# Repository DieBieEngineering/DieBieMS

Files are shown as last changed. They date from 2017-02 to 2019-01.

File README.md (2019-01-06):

DieBieMS - Hardware
===
# Introduction
My personal transportation environment is becoming more and more electrical. All my new vehicles so far contain Lithium based batteries and need some form of automated management to be utilized in a safe and easy way. All affordable alternatives that I could find were either to dangerous(extreme cell voltage limits), couldn't carry the desired current (>70A), not compact enough or were not customizable. With this fully opensource project I would like to contribute to a more safe and affordable Lithium based electric vehicle (or possible other usage) future.

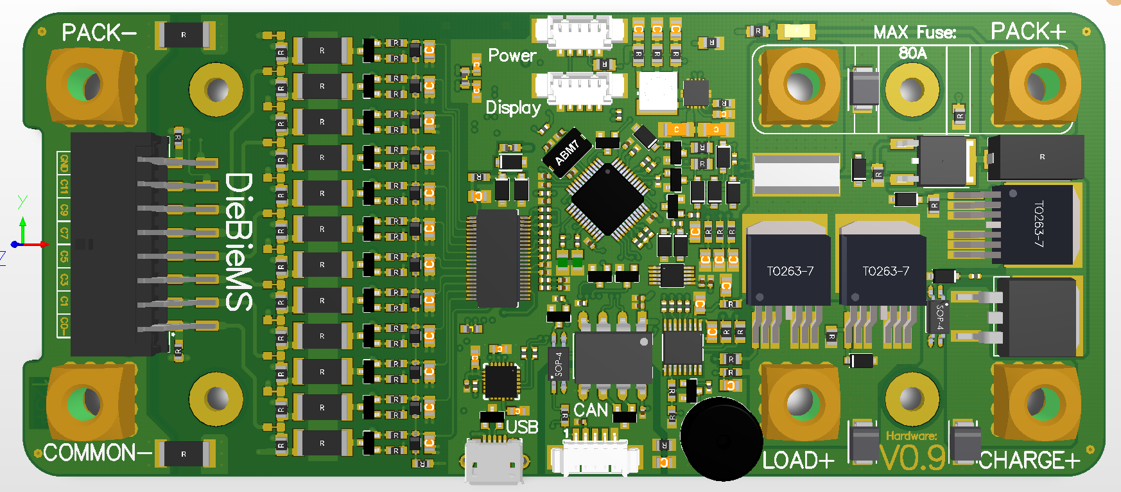
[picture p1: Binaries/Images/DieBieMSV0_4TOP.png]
DieBieMS V0.4 TopView


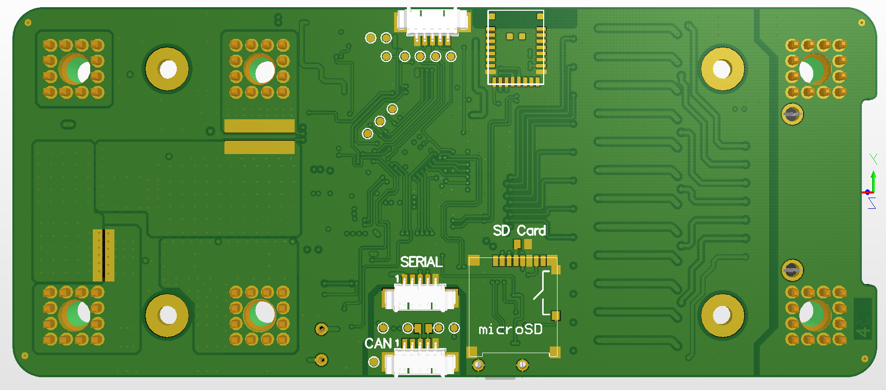
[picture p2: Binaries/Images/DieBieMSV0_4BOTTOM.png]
DieBieMS V0.4 BottomView


### Other parts of this project
This is the hardware repository containing all hardware source files (designed in altium) and the project outputs to build a BMS PCB. There are three more repositories for this project:<br>
[DieBieMS Firmware](https://github.com/DieBieEngineering/DieBieMS-Firmware) has to be flashed to the empty BMS STM32, the build .bin and hex file can be found in the BMS tool [resource folder](https://github.com/DieBieEngineering/DieBieMS-Tool/tree/master/res/firmwares).<br>
[DieBieMS Bootloader](https://github.com/DieBieEngineering/DieBieMS-Bootloader) can be flashed with the BMS Tool in the firmware tab.<br>
[DieBieMS Configuration tool](https://github.com/DieBieEngineering/DieBieMS-Tool) the tool to configure the BMS and upload the bootloader / update the main firmware.<br>

### Latest hardware release (production files)
Production data for most recent version can be found [here](Project%20Outputs%20for%20DB10005_DieBieMS). The initial project blog/log can be found [here](http://www.electric-skateboard.builders/t/diy-6s-to-12s-bms-with-can/2639). And the schematic in PDF [here](Project%20Outputs%20for%20DB10005_DieBieMS/DB10005_DieBieMS.PDF).

### Features
This BMS is an all in one solution, combined with a lithium battery it is possible to replace an existing lead based battery pack (ideal for upgrading a bulky and heavy electric scooter with a much lighter li-polymer pack). In order to be a plug and play system the BMS carries all power electronics and controller systems to switch the main power path and communicate with external interfaces (displays, buttons or anything else you adapt to it). A small list of features:

* Soft power switch input with LED (LOAD) on/off + charge indicator.
* High side power switching to allow all grounds to remain connected at all times.
* Charge input -> switched (high side) -> to charger output (to disable charger if a cell reaches the max cell voltage).
* Charge input has optional input diode to eliminate current leakage or power on exposed pins (like the male charge connector). V0.10 is an experimental version that has a P-FET instead of the diode to limit heat production when charging.
* Discharge input -> switched (high side)-> to LOAD e.i. motor controller / VESC (to disable the load when a cell reaches the min voltage).
* Isolated CAN bus interface for cell voltage monitoring and charger detection, status monitoring + much more with future updates (like state of charge / state of health).
* Pack current sensing (bi-directional).
* Pre charge for high capacitive load (with shortcircuit detection, in case the motor controller is shorted / dead / wrong polarity).
* USB interface for serial communication and firmware upgrades (no need for a programmer -> HW serial bootloader is used).
* Buzzer to indicate possible Error state.
* Compact footprint

### Electrical specifications
* Max load current +/- 100A for a short time, for long it is about 70A.
* Max charge current 10A (with diode) or 30A (with diode bypass).
* Cell voltage range 2.5V to 4.5V.
* Pack voltage 12V to 54V

# Realisation
Out of the many ways to realise an all in one BMS I chose the more simple but maybe more expensive way. Since there is a lot of desired functionality and the need for a small footprint many features are realized by complex chips.

#### Power-on state management
There are several ways to enable the BMS and put it into the corresponding operation mode. As of now the following modes of operation are present:
* Normal operation

   This mode is triggered by a single pres on the powerbutton, when the button is released the microcontroller keeps the BMS on. A long pres will powerdown the BMS. The LED turns solid on when enabled and turn off when powerdown long buttonpress is detected.
* Charging mode

   When the CHARGE+ input is brought >3V above the PACK+ terminal the BMS is booting into charge mode, the microcontroller will check the cell voltages and if desired enable the switch to allow current to flow from CHARGE+ to PACK+. In this mode the microcontroller knows the presence of the charge. If the charger is removed the microcontroller will keep the BMS on for a configurable amount of time to display a status message (show for example the charged amount) followed by powering down.
* External mode

   When a USB cable is connected or 5V is applied on the CAN connector the BMS will boot into external power mode. Firmware updating trough the hardware bootloader or communication over CAN bus is now possible. The power on enable by CAN functionality allows an externally battery powered telemetry device to enable the BMS and request battery pack data (giving for example daily / weekly / monthly status updates).

#### Used technology
The IC's used with their corresponding functionality:
* LTC6803-2 -> Battery stack cell voltage monitor.
* STM32F303 -> Main microcontroller.
* ISL28022 -> Pack voltage and current measurement.
* BQ76200 -> Height side FET driver for LOAD+ CHARGE+ and Pre-charge switch driving.
* LM5165 -> SMPS Buck converter, converting the pack voltage to +3.3V.
* ISO1050 -> isolated CAN-Bus transceiver.
* CP2104-F03 -> USB to serial converter for bootloader based firmware updates and debugging.

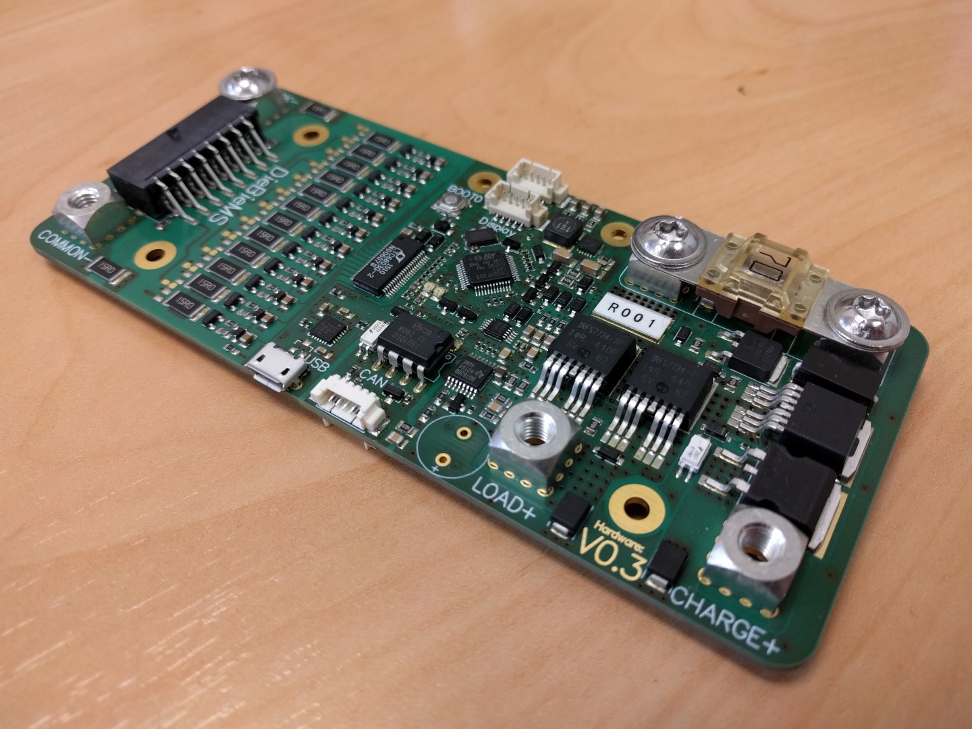
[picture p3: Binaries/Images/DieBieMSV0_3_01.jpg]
DieBieMS V0.3 Overview


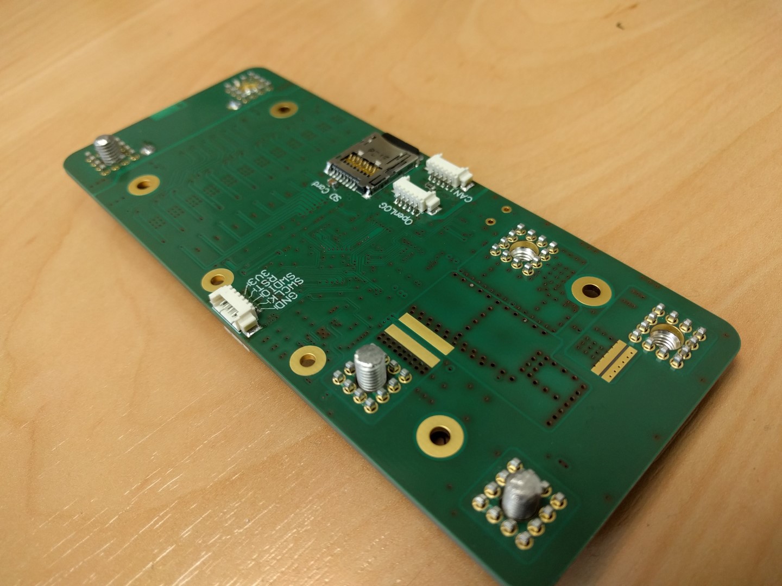
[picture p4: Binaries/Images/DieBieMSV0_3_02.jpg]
DieBieMS V0.3 BottomView


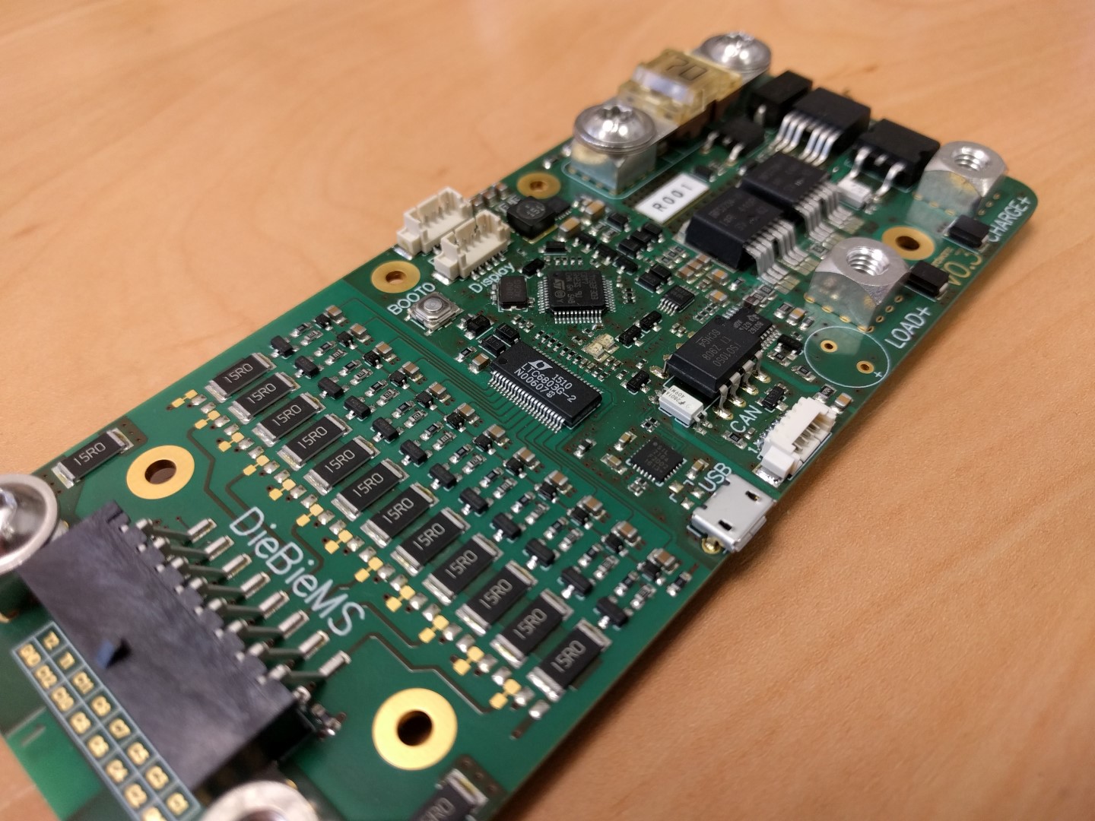
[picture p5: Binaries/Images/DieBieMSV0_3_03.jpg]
DieBieMS V0.3 Balance resistors


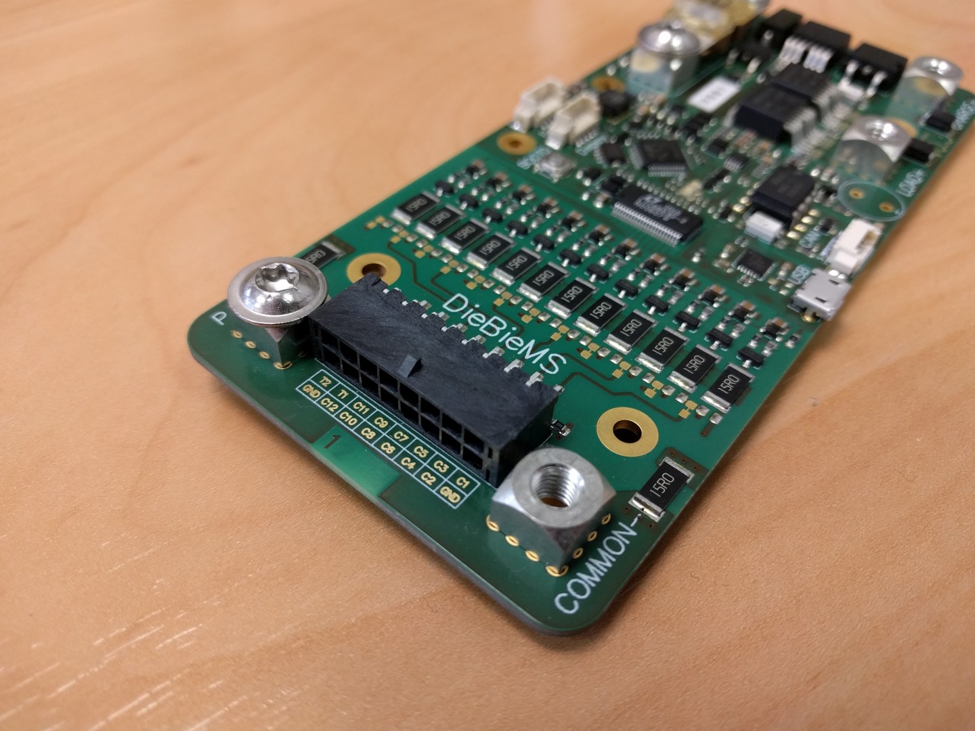
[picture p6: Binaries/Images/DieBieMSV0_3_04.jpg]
DieBieMS V0.3 Celltap connector


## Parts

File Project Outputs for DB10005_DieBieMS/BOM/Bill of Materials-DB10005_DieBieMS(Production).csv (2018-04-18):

Quantity | Designator | LibRef | Order Code Supplier | Description | Footprint | Supplier
16 | C20, C21, C22, C25_CELL1, C25_CELL2, C25_CELL3, C25_CELL4, C25_CELL5, C25_CELL6, C25_CELL7, C25_CELL8, C25_CELL9, C25_CELL10, C25_CELL11, C25_CELL12, C37 | 100nF/0805/CER/100V | 1650862 | Capacitor, 100nF, 100V, X7R | C-0805 | Farnell
15 | R26, R32, R36_CELL1, R36_CELL2, R36_CELL3, R36_CELL4, R36_CELL5, R36_CELL6, R36_CELL7, R36_CELL8, R36_CELL9, R36_CELL10, R36_CELL11, R36_CELL12, R63 | 100/0603/0063W/50V | 2122239 | Resistor, 100R, 1%, 0.063W, 50V, 200PPM, 0603 | 0603 | Farnell
14 | R6, R7, R38_CELL1, R38_CELL2, R38_CELL3, R38_CELL4, R38_CELL5, R38_CELL6, R38_CELL7, R38_CELL8, R38_CELL9, R38_CELL10, R38_CELL11, R38_CELL12 | 15/2512/2W/250V | 2117454 | Resistor, 15R, 1%, 2W, 200V, 200PPM, 2512 | 2512 | Farnell
12 | D23_CELL1, D23_CELL2, D23_CELL3, D23_CELL4, D23_CELL5, D23_CELL6, D23_CELL7, D23_CELL8, D23_CELL9, D23_CELL10, D23_CELL11, D23_CELL12 | PDZ7.5B | 2319197 | Diode, Vrrm: 7.5V, If: 0.2A, Vf: 0.9V | SOD-323 | Farnell
12 | Q5_CELL1, Q5_CELL2, Q5_CELL3, Q5_CELL4, Q5_CELL5, Q5_CELL6, Q5_CELL7, Q5_CELL8, Q5_CELL9, Q5_CELL10, Q5_CELL11, Q5_CELL12 | TSM2323 | 1864590 | Mosfet, P-channel, Vds:20V, Id:4.7A, Vgs-th:1V, Rds-on:0.039ohm | SOT-23 | Farnell
12 | R37_CELL1, R37_CELL2, R37_CELL3, R37_CELL4, R37_CELL5, R37_CELL6, R37_CELL7, R37_CELL8, R37_CELL9, R37_CELL10, R37_CELL11, R37_CELL12 | 3.3K/0603/0125W/50V | 1576291 | Resistor, 3.3K, 1%, 0.125W, 50V, 100PPM, 0603 | 0603 | Farnell
11 | C1, C2, C3, C4, C5, C11, C14, C17, C27, C28, C42 | 100nF/0402/CER/25V | 2456106 | Capacitor, 100nF, 25V, X7R | C0402 | Farnell
11 | R1, R12, R22, R23, R24, R25, R47, R48, R53, R54, R68 | 10k/0402/0063W/50V | 2121730 | Resistor, 10k, 0.1%, 0.0625W, 50V, 100PPM, 0402 | 0402 | Farnell
8 | D5, D13, D14, D15, D16, D19, D21, D22 | MMSD4148T1G | 9556079 | Diode, Vrrm: 100V, If: 0.15A, Vf: 1V | SOD123 | Farnell
8 | Q6, Q7, Q8, Q9, Q10, Q11, Q12, Q13 | BSS123 | 1510764 | Mosfet, N-channel, Vds:100V, Id:0.15A, Vgs-th:2.8V, Rds-on:3.5ohm | SOT-23 | Farnell
7 | C12, C13, C29, C38, C39, C40, C41 | 1uF/0402/CER/6.3V | 1327658 | Capacitor, 1uF, 6.3V, X5R | C0402 | Farnell
7 | R57, R58, R59, R60, R61, R62, R73 | 1M/0402/0063W/50V | 2121984 | Resistor, 1M, 0.1%, 0.0625W, 50V, 100PPM, 0402 | 0402 | Farnell
6 | J1, J2, J3, J4, J5, J8 | 7460408 | 1821279 | Bush with Circumference M5 | 7460408_HAL Surface | Farnell
6 | R10, R30, R31, R34, R42, R43 | 4.7M/0805/0250W/150V | 1576516 | Resistor, 4.7M, 1%, 0.25W, 150V, 100PPM, 0805 | 0805 | Farnell
6 | R13, R14, R18, R19, R20, R49 | 4.75k/0402/0063W/50V | 2121689 | Resistor, 4.75k, 0.1%, 0.0625W, 50V, 100PPM, 0402 | 0402 | Farnell
5 | D10, D11, D12, D17, D18 | BZT52C16 | 1902431 | Diode Zener, Vz: 16V, If: 0.1A, Vf: 0.9V | SOD123 | Farnell
4 | C19, C23, C24, C30 | 10nF/0805/CER/100V | 1301898 | Capacitor, 10nF, 100V, X7R | C-0805 | Farnell
4 | J6, J9, J10, J16 | 53261-0571 | 1125360 | PicoBlade 53261 Series, 5Pin, Right Angle | 53261-0571 | Farnell
4 | R3, R27, R28, R35 | 100/0805/0250W/150V | 1576445 | Resistor, 100R, 1%, 0.25W, 150V, 100PPM, 0805 | 0805 | Farnell
4 | R9, R29, R67, R70 | 470/0402/0063W/50V | 2331533 | Resistor, 470, 1%, 0.0625W, 50V, 100PPM, 0402 | 0402 | Farnell
3 | C15, C16, C18 | 2.2uF/0603/CER/16V | 1735526 | Capacitor, 2.2uF, 16V, X5R | C0603 | Farnell
3 | C34, C35, C36 | 10uF/0805/CER/10V | 1828828 | Capacitor, 10uF, 10V, X7R | C-0805 | Farnell
3 | D8, D9, D25 | SMBJ70A-TR | 9886389 | Diode TVS, Vrwm: 70V, Vbr: 81.9V, Vc: 113V, Ippm: 27A | SMB | Farnell
3 | Q1, Q2, Q3 | IRFS7530-7PPBF | 2580027 | Mosfet, N-channel, Vds:60V, Id:338A, Vgs-th:3.7V, Rds-on:0.00115ohm | D2PAK7 | Farnell
3 | R15, R16, R17 | 10/0603/0063W/50V | 2122113 | Resistor, 10R, 1%, 0.063W, 50V, 200PPM, 0603 | 0603 | Farnell
3 | R41, R44, R45 | 1/0805/0250W/150V | 1717826 | Resistor, 1R, 1%, 0.25W, 150V, 200PPM, 0805 | 0805 | Farnell
3 | R52, R56, R65 | 0/0603/0063W/50V | 2122112 | Resistor, 0R, 0.1%, 0.063W, 50V, 200PPM, 0603 | 0603 | Farnell
3 | R8, R50, R51 | 100k/0402/0063W/50V | 2121857 | Resistor, 100k, 0.1%, 0.0625W, 50V, 100PPM, 0402 | 0402 | Farnell
2 | C31, C32 | 1uF/1206/CER/100V | 1833855 | Capacitor, 1uF, 100V, X7R | C-1206 | Farnell
2 | C7, C43 | 2.2uF/0805/CER/50V | 2611933 | Capacitor, 2.2uF, 50V, X7R | C-0805 | Farnell
2 | C9, C10 | 18pF/0402/CER/50V | 1828876 | Capacitor, 18pF, 50V, NP0 | C0402 | Farnell
2 | D2, D6 | HMHA2801 | 1652504 | Optocoupler, Vout:80V, Iin:0.01A | FSOP4 | Farnell
2 | D4, D24 | KP-2012SGC | 1318243 | Led, Green, Li:12mcd, Vf:2.2V, If:0.02A | D-0805 | Farnell
2 | J13, J14 | 53398-0571 | 1125354 | PicoBlade 53398 Series, 5Pin, Right Angle | 53398-0571 | Farnell
2 | R2, R40 | 2.2K/0603/0063W/50V | 2122405 | Resistor, 2.2K, 1%, 0.063W, 50V, 100PPM, 0603 | 0603 | Farnell
2 | R4, R5 | 240/0402/0063W/50V | 2121522 | Resistor, 240, 0.1%, 0.0625W, 50V, 100PPM, 0402 | 0402 | Farnell
2 | R66, R72 | 1.5k/0402/0063W/50V | 2121624 | Resistor, 1.5k, 0.1%, 0.0625W, 50V, 100PPM, 0402 | 0402 | Farnell
1 | C33 | 47nF/0603/CER/50V | 1759116 | Capacitor, 47nF, 50V, X7R | C0603 | Farnell
1 | D1 | ESDA6V1L | 9802258 | Diode TVS Dual, Vrwm: 5.25V, Vbr: 7.2V, Vc: 12.45V, Ippm: 15A | SOT23 | Farnell
1 | D20 | BZT52H-C62,115 | 1757813RL | Diode Zener, Vz: 62V, If: 0.25A, Vf: 0.9V | SOD123W | Farnell
1 | D3 | SP0502BAHTG | 1827631 | Diode TVS Dual, Vrwm: 5.5V Vc: 8V | SOT23 | Farnell
1 | D7 | STPS41H100CG | 2353681 | 100 V, 40 A, TO-263, 3 Pins, 900 mV | D2-PAK | Farnell
1 | F1 | 0466.200NR | 1596522 | Fuse, Slow Blow, 200 mA, 125 VAC, 125 VDC | F1206 | Farnell
1 | IC1 | STM32F303CCT6 | 2215113 | MCU, 32BIT CORTEX-M3, 72MHz | LQFP48 | Farnell
1 | IC3 | LM5165Y | 595-LM5165YDRCT | Buck Vreg 150mA 3V3 out 5-65Vin | PWSON10 | Mouser
1 | IC4 | ISO1050DUBR | 1755712 | CAN TRANSCEIVER | PDSO8 | Farnell
1 | IC5 | CP2104-F03-GM | 757-4983 | USB to UART converter | QFN24 | RS-Components
1 | IC6 | ISL28022 | 2373594 | Current and voltage ADC | MSOP10 | Farnell
1 | IC7 | BQ76200PW | 2522565 | Battery protector, Lead Acid | TSSOP16 | Farnell
1 | J12 | 662016230822 | 2113471 | WR-MPC3 Series, Surface Mount, Header, 16 Contacts, 3 mm | 662016230822 | Farnell
1 | J7 | USB3075 | 2443116 | USB 2.0 MICRO B, RCPT, 5POS, SMT | USB3075 - NOSLOT | Farnell
1 | L1 | 744043151 | 2082517 | 150UH, 30%, 0.42A | WE-TPC 4828, MH | Farnell
1 | L2 | BLM18PG330SN1D | 1515742 | Ferrite Bead, Impedance:33ohm, DC Resistance Max:0.025ohm, DC Current Rating:3A | L0603 | Farnell
1 | Q4 | IRFR6215TRPBF | 1839002 | Mosfet, P-channel, Vds:150V, Id:13A, Vgs-th:4V, Rds-on:0.295ohm | D-PAK | Farnell
1 | R11 | FCSL110R001JER | 2420535 | 1mohm, 5 W, ± 5%, 4320 Wide | FCSL110 | Farnell
1 | R21 | 33K/0603/0063W/50V | 2122555 | Resistor, 33K, 1%, 0.063W, 50V, 100PPM, 0603 | 0603 | Farnell
1 | R33 | 18 | 1086385 | Resistor Wirewound, 18R, 5%, 3W, 500V, 200PPM, SMW | SM_3 | Farnell
1 | R46 | 130K/0603/0063W/50V | 2122632 | Resistor, 130K, 1%, 0.063W, 50V, 100PPM, 0603 | 0603 | Farnell
1 | R55 | 15/0805/0125W/150V | 9233784 | Resistor, 15R, 0.1%, 0.125W, 150V, 15PPM, 0805 | 0805 | Farnell
1 | R74 | NTCS0805E4104JMT | 1187095 | THERMISTOR, NTC, 100K, 5% | 0805 | Farnell
1 | U1 | LTC6803-2 | 858-0829 | Multicell Battery Stack Monitor, T:-40°C to +85°C | SSOP44 | RS-Online
1 | U2 | AI-1027-TWT-5V-2-R | 665-AI1027TWT5V2R | EM 5VDC 2300Hz 82dBA Continuous Top Fire | AI-1027-TWT | Mouser
1 | X1 | ABM3-8.000MHZ-D2Y-T | 2101329 | 8MHZ, 18PF, 5 X 3.2MM | XTAL150SMD_125X196 | Farnell

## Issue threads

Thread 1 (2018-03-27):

Specifications

happytm, 2018-03-27:
What are the specifications for this board? specially compared to http://electrodacus.com/SBMS100/manual/SBMSmanual.pdf

lpasselin, 2018-04-29:
> Solar BMS can be used with 3 up to 8 Lithium cells (any type)

Most DIY kits are 10S with 18650.

SBMS is less convenient as an electric skateboard BMS.

DieBieEngineering, 2018-10-04:
It is indeed oriented towards smal electric vehicles with their corresponding size and functional requirements.

Closed 2018-10-04.

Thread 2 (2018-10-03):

Understanding Problem? (R39)

andig91, 2018-10-03:
Hello!

The last days I have seen your BMS.
Fully interested I have looked at the scematic.

Is there anywhere a description of the different parts or can you answer me few questions?

Now one question. For what is R39, its look like shorting the cell.
Should it a solder brigde? It isn't in BOM.
I don't have enough experience in altium for "understanding the whole schematic".

When you say BMS from 6S to 12S.
When I am connection different series of packs need i have to solder R39 on unused cells?
Or is this only software config?

Why is 6S the minimum?
Or isn't it? Only 12V?

I hope you can help me.
Thank you a lot.
Regards
Andy

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

DieBieEngineering, 2018-10-04:
Hi!

Sorry no description or manual yet, due to the hierarchical schematic build it should be relatively ok to read / understand.

R39 is an option to bypass a cell measure an balance input. When for example using the bms with a 8S battery you should according to the LTC6803 specification short the unused cell inputs (in the 8S case the top 4 cell inputs), this can be done with R39 (there are 12 instances of the cell balance schematic you posted with all "jumper" / bypass 0R resistors called R39 ).

In the PCB production output files and the production variant the R39 is stated as non populated.

The 6S to 12S states the "usable" range (where the currents are normally acceptable), It can operate from 4S to 12S but the low / empty battery voltage tends to get really low for the power supply to operate. If I remember correctly there is also a minimal voltage requirement for the LTC.

So far in 95% of all application I never populate R39, the BMS and thus LTC performs just fine with the inputs open.

Closed 2019-03-17.

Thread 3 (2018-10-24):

What fuser are you using?

rahmaevao, 2018-10-24:
The photo shows a large fuse, but it is not in bom.
What fuser are you using?

b264, 2018-10-25:
Is it one of these? https://www.amazon.de/Leistungssicherung-Streifensicherung-Sicherung-Midi-weiss/dp/B00EBNRXRK/ref=mp_s_a_1_4

Closed 2019-03-11.

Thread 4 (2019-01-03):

Update DieBieMS Readme

tojon, 2019-01-03:
The Readme could be improved with a couple of quick typo fixes and removes some trailing white space. Feel free to use the upcoming PR or just close this Issue and PR and wrap the changes into your own work :)

tojon, 2019-01-03:
So we've merged this change, and @DieBieEngineering will do additional work in is own subsequent PRs. Marking this Issue as fixed and Closed.

tojon, 2019-01-03:
Actually I think Danny might need to do this for best practice, since he's the Repo Owner and I don't have project permissions.

DieBieEngineering, 2019-01-03:
The suggested changes are merged, thanks for the assistance!

Closed 2019-01-03.

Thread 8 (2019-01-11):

BMS

SwiftFlying, 2019-01-11:
Hi,
I am TOM from China. I am interested in BMS. Are you interested in our cooperation in developing a commercial BMS?

DieBieEngineering, 2019-03-17:
Hi! You are free to use all files in any way or kind and resell it ( but please use genuine and real parts, although sometimes expensive....) .

I have multiple projects going, maybe in the future I'll make it more compact and cheaper, nothing on the short term I am afraid.

Closed 2019-03-17.

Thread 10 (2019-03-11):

Why do we need R6, R7?

rahmaevao, 2019-03-11:
It is resistors very power. Why do we need R6, R7?

DieBieEngineering, 2019-03-17:
Damage control in case of wrongly connecting the BMS in some situations. In normal use your don't need them, but they saved my and others ass multiple times.

rahmaevao, 2019-03-18:
Thanks

Closed 2019-03-18.

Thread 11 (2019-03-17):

Diode D5? One or two shunts?

BluePygmyOwl, 2019-03-17:
Hi Danny,
Big comliments on this. It looks really nice, and I thought I might give it a try to build this myself.

When I looked at the schematic, I had some questions.
- When a charger is plugged in, Chargedetect is pulled low. The voltage difference between charger and battery will turn on the optocoupler D2. First I thought D5 was some Zener Voltage Regulator diode, but then I saw that it isn't a zener. Why is D5 there then?

- Also, in the schematic you have R11 and R64 as shunt resistors (1mOhm), but on the pictures I only see one shunt placed on your boards. R11 is rated for 5W. Isn't that short when using proper discharge loads (electric board)? If R64 is added, does this imply a software setting that has to be changed?
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

Thanks in advance

DieBieEngineering, 2019-03-18:
The two shunts are there to allow for different component population options ( to experiment ). In the Altium project you can select population variants, with every variant I made the I always have only the top shunt mounted.

I can totally imagine how strange it looks! Some LEDs can handle only a limited voltage in the reverse direction, this diode prevents that voltage to be created. This circuit also changes in a evaluation branch ( HW V0.10 ), there I also implement a P fet as ideal input diode.

BluePygmyOwl, 2019-03-18:
Hi Danny,
Thanks. Should I wait with my build for V0.10? Or does that take some significant time before you can publish? I am kind of amped to start to build this, but I do like the idea of the ideal input diode. Will you use a comparator instead of the opto for ChargeDetect?

DieBieEngineering, 2019-03-18:
It is already in GitHub on a branch, I will look it up and let you know. It
is also tested and works!

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

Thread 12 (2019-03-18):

Not saved config

rahmaevao, 2019-03-18:
I saved motor configuration in DieBieMS tool, but after reconnect battery my config set to default.

rahmaevao, 2019-03-18:
Need click button "Store BMS configuration to flash".

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

Closed 2019-03-18.

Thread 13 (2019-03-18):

How turn on this BMS?

rahmaevao, 2019-03-18:
Hi. I assembled the device.
HW 0.8
I connected battery. I upload firmware. Device connecting in DieBieMSTool.
I connect pin J14:2 to GND. Terminal DieBieMS says the button is pressed.

> -----Battery Pack Status-----
Pack voltage          : 24.52V
Pack current          : 0.04A
Low  current          : 0.04A
High current          : 0.00A
State of charge       : 0.0%
Remaining capacity    : 0.00Ah
Operational state     : Power down
Load voltage          : 0.00V
Cell voltage high     : 3.506V
Cell voltage low      : 3.503V
Cell voltage average  : 3.505V
Cell voltage mismatch : 0.003V
Discharge enabled     : False
Charge enabled        : False
Power button pressed  : True
---End Battery Pack Status---

But BMS not connected LOAD and battery. OpState remains Power down.

How turn on this BMS?

DieBieEngineering, 2019-03-18:
Ok ltc seems to work and ISL as well!

However the power button should not indicate pressed unless it is actually
pressed. You don't have a button connected right?

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

rahmaevao, 2019-03-19:
Thanks for the quick feedback.
I really like this BMS.
> Ok ltc seems to work and ISL as well!

Yes, it work.

> However the power button should not indicate pressed unless it is actually
> pressed. You don't have a button connected right?

I not have special button, but i connect pin 2 J14 connector to pin 1 J14 connector.
If i connect pin 2 to pin 1, terminal says "Power button pressed  : True".
If pin 2 is not connected to pin 1,  terminal says "Power button pressed  : False".

DieBieEngineering, 2019-03-19:
Ok in that case it works as it should. The power button input should be a
momentary switch.

I'll explain a bit more in a sec. Did you also find the skateboard forum?

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

rahmaevao, 2019-03-20:
Oh, Denny. Your forum not acessed in my region (Russia). Proxy in my provider not let throgh vpn.
I use cashe google for reading forum.((

rahmaevao, 2019-03-21:
Oh, my BQ76200PW destroyed.
I changed it and everything works.

Closed 2019-03-21.

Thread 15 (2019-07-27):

Power cutting off. Vesc indicating low vaultage Fault

Wraith3333, 2019-07-27:
When running on the bench, everything works fine but the moment I step on the board, power is cut off to the vescs and the board dies. Checked all the wiring and updated to v.27. running 16Ah 10s6p Li-ion pack with DBMS

DieBieEngineering, 2019-07-27:
Do you have pictures of your setup?

Can you video the BMS tool showing the real-time cell voltages?

Sounds like a wiring issue or a low voltage cutoff...

Wraith3333, 2019-07-29:
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

The wiring is solid, nothing loose. It cuts off randomly on the bench as well without any load. I can't upload videos but I've attached a screenshot of the Realtime Data

Wraith3333, 2019-08-02:
Switching on the board with the display of the bms connected shows random shut offs with the display showing "bye" the same way it would when manually shutting it down via a power switch

Wraith3333, 2019-08-02:
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
unsure why the values indicate fail when running testbms on the terminal. could this be the reason for the shut off

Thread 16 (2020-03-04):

SAFETY Signal on GPIO2

DanieGieb, 2020-03-04:
Hello,

first of all really nice project! I am currently making a special Version for a custom battery pack.
So thank you very much for sharing!

I have a question:
What is the purpose for connecting the SAFETY signal to GPIO2 of the LTC6803?
I guess its for the reason when something went wrong with communication due to a uC brownout for example?
But why did you use GPIO2 for that? I think the WDTB pin is a better choice for that?
Like the datasheet suggests on page 15:

> WATCHDOG TIMER CIRCUIT
The LTC6803 includes a watchdog timer circuit. The watchdog timer is on for all modes except CDC = 0. The watchdog timer times out if no valid command is received for 1 to 2.5 seconds. When the watchdog timer circuit times out, the WDTB open-drain output is asserted low and the configuration register bits are reset to their default (power-up) state. In the power-up state, CDC is 0, the S outputs are off and the IC is in the low power standby mode. The WDTB pin remains low until a valid command is received. The watchdog timer provides a means to turn off cell discharging should communications to the MPU be interrupted. There is no need for the watchdog timer at CDC = 0 since discharging is off. The open-drain WDTB output can be wire ORd with other external open-drain signals. Pulling the WDTB signal low will not initiate a watchdog event, but the CNFGO bit 7 will reflect the state of this signal. Therefore, the WDTB pin can be used to monitor external digital events if desired.

If using GPIO2 and the uC sets this pin to zero, the power stage can be switched on. When the uC gets stucked or something went wrong the pin stays at low level, so the power stage will remain enabled!?
This would not happen if SAFETY is connected to the WDTB pin, which uses the LTC6803 internal watchdog?

Or is there any special purposes why you used GPIO2?

Here is my current implementation of the WDTB watchdog feature:
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

This also has the additional advance that the ISL28022 can also interrupts discharge/charge if an error occurs. (Overcurrent for example).
I think this should be much faster than doing this with the uC.
And once the ISL28022 is successfully configured and the software later stucks the overcurrent protection is still available.

Kind Regards
Danie

DieBieEngineering, 2020-03-06:
This is a system to disable the out and input when the watchdog triggers of the LTC (the LTC resets also its GPIO on WDT overflow). I use an GPIO on the LTC because over SPI I tell the LTC to pull the wire low (low being the charge / discharge are allowed to become high). So this is exactly as you have understood it operates.

The drawback of using the WDT is that it works the other way around, and you dont have a clear understanding of why the pin is asserted (any communication that is valid will reset the WDT if I recall correctly), where in the GPIO approach you have the uC deliberately ask the pin to go low.

( I actually first build it with the use of the WDT pin, but then moved to using the GPIO because of the added features described )

DanieGieb, 2020-03-06:
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

That clearly makes sense to me! You are right - any valid communication will reset the WDT!
Thank you for your explanation!
I will use GPIO2. Because i don't have space for the SD card i will connect the WDT pin to the uC.
The ISL Interrupt signal is open drain, so i will connect it over 0R to the Safety signal.
So the ISL can also disable the charge and discharge FETs.
I think this will add another good safety feature to the device, because after the ISL is successfully configured, the software can stuck and overcurrent over- and undervoltage cutoff is still possible by hardware.

Another short question:
Is there a UART left on the STM? I plan to implement a connector for a serial bluetooth interface module like the cheap HC05, because the SPI wireless module is not available in germany :/
Could the mobile app of the BMS tool use this bluetooth connection or is connection only possible with your implemented wireless module?
I think this should work!?

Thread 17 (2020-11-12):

Current trough pcb

Xavoy, 2020-11-12:
Hi,

first of all i'd like to congratulate you for this awesome proyect.
I have been analyzing the project and i have a doubt about the charging mode, specifically where you say "**if desired enable the switch to allow current to flow from CHARGE+ to PACK+**". I do not know how much current flows through the pcb for charging but i think is about 2-10 amps if this BMS is used for electrical vehicles. With 10 amps we need a very wide track on the PCB but i do not see in the model. Is there something that i am not counting on?
I have a parallel doubt with the discharging mode. There is a fuse of 80 amps between B+ and BATT+ but later the track is not specially wide...
Maybe this questions are too obvious but i'm new in designing electronics xD

Thank you and best regards

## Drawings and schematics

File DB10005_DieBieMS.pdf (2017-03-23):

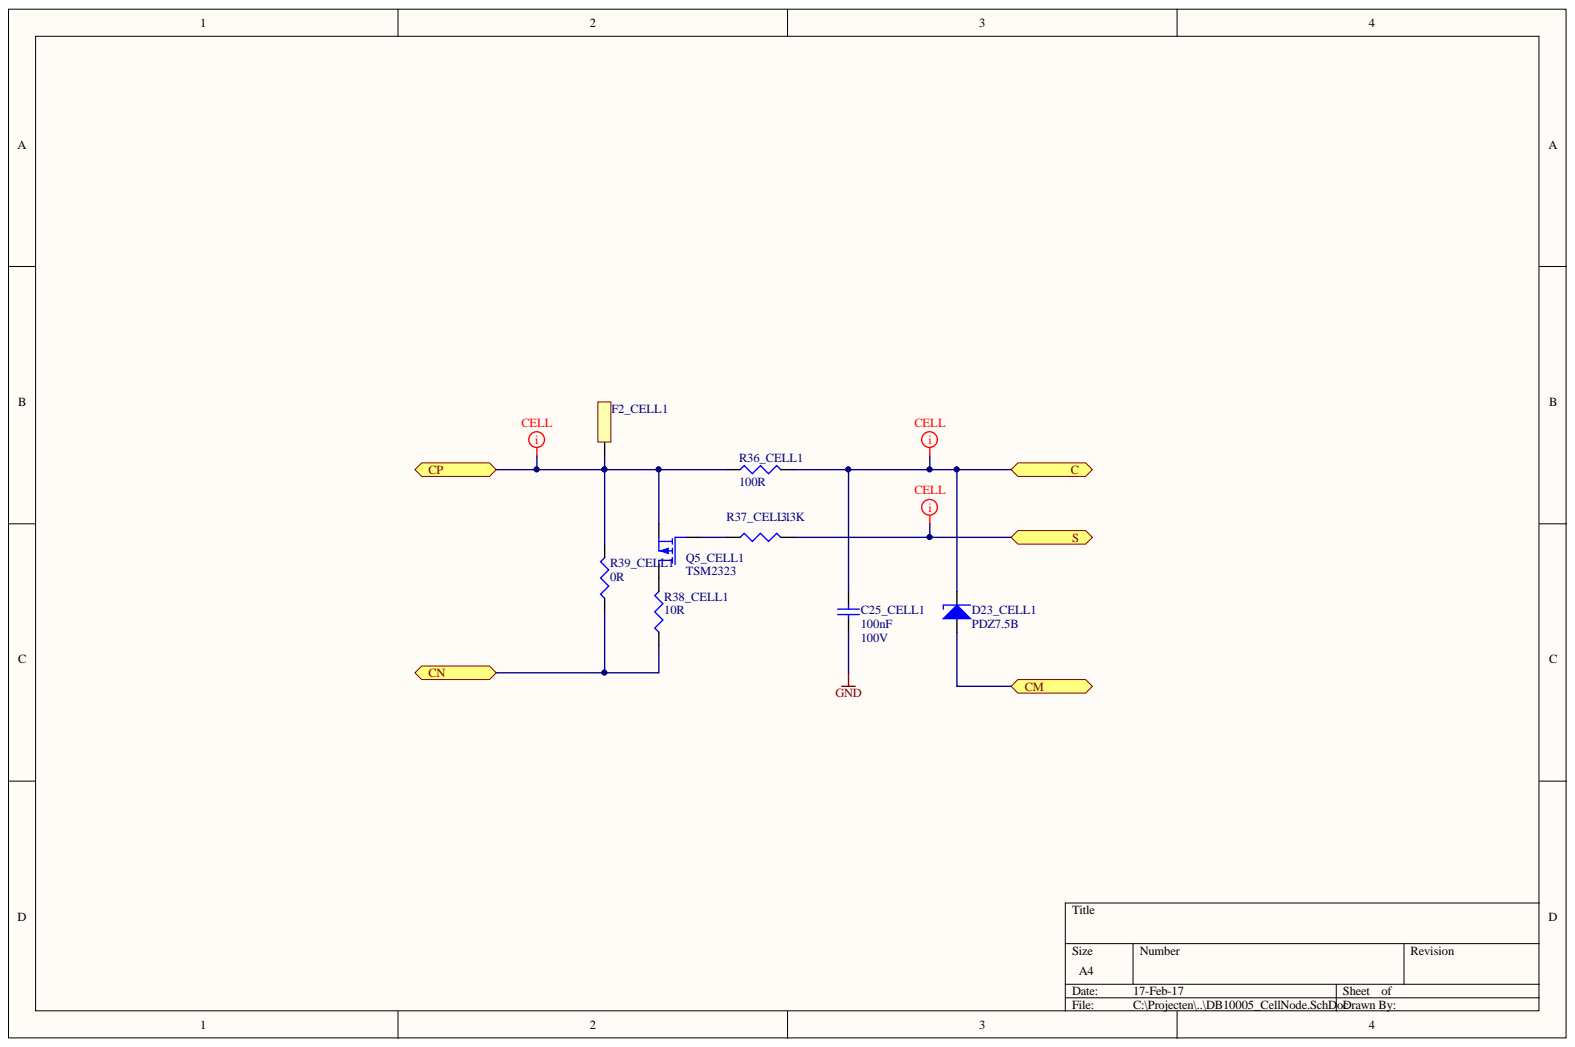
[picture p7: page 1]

Size A4 | Number | Revision

Date: 17-Feb-17 | Sheet of
File: C:\Projecten\..\DB10005_CellNode.SchDocDrawn By:

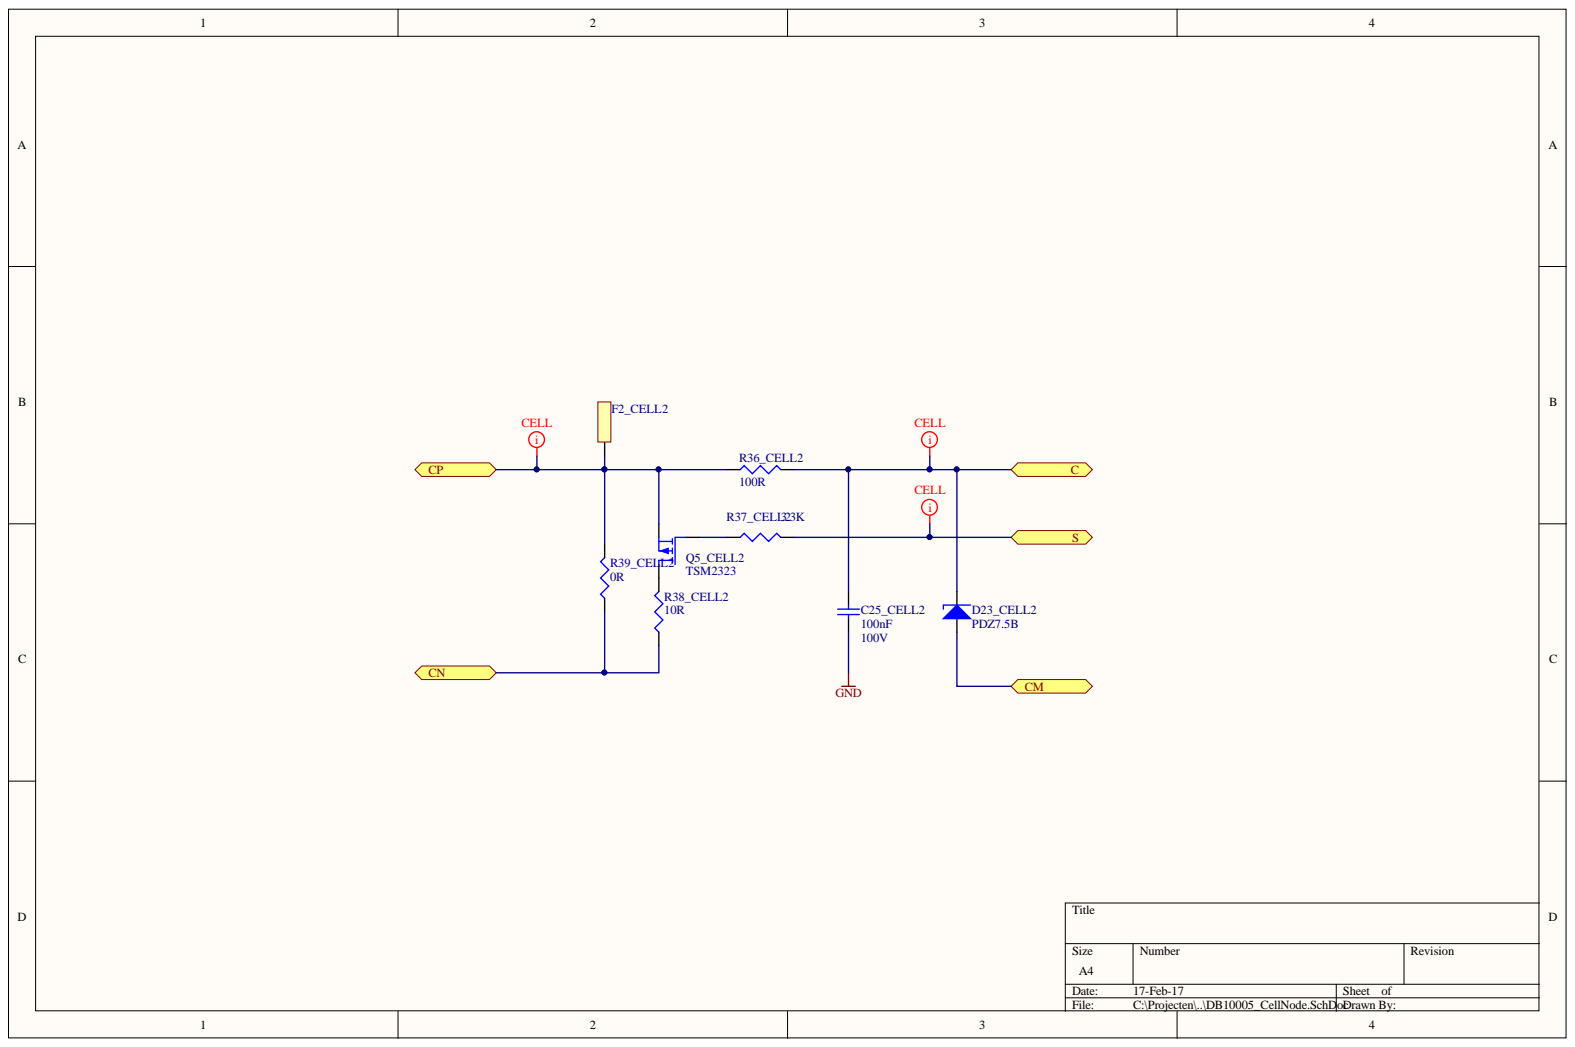
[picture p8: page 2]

Size A4 | Number | Revision

Date: 17-Feb-17 | Sheet of
File: C:\Projecten\..\DB10005_CellNode.SchDocDrawn By:

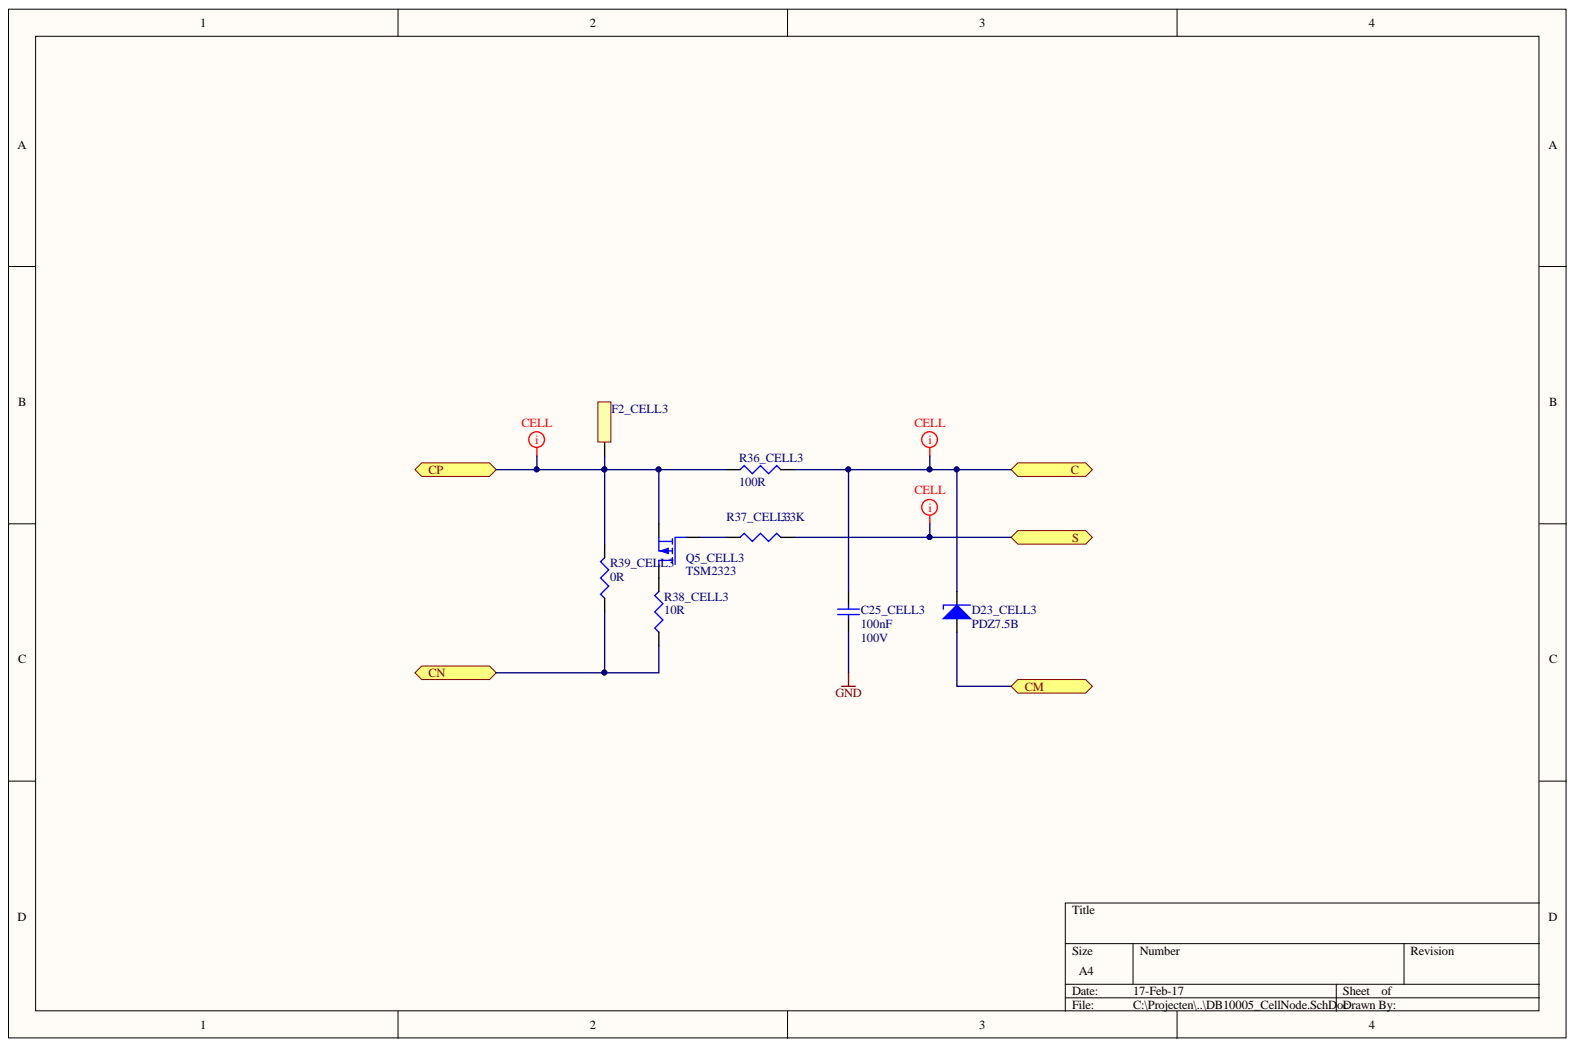
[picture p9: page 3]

Size A4 | Number | Revision

Date: 17-Feb-17 | Sheet of
File: C:\Projecten\..\DB10005_CellNode.SchDocDrawn By:

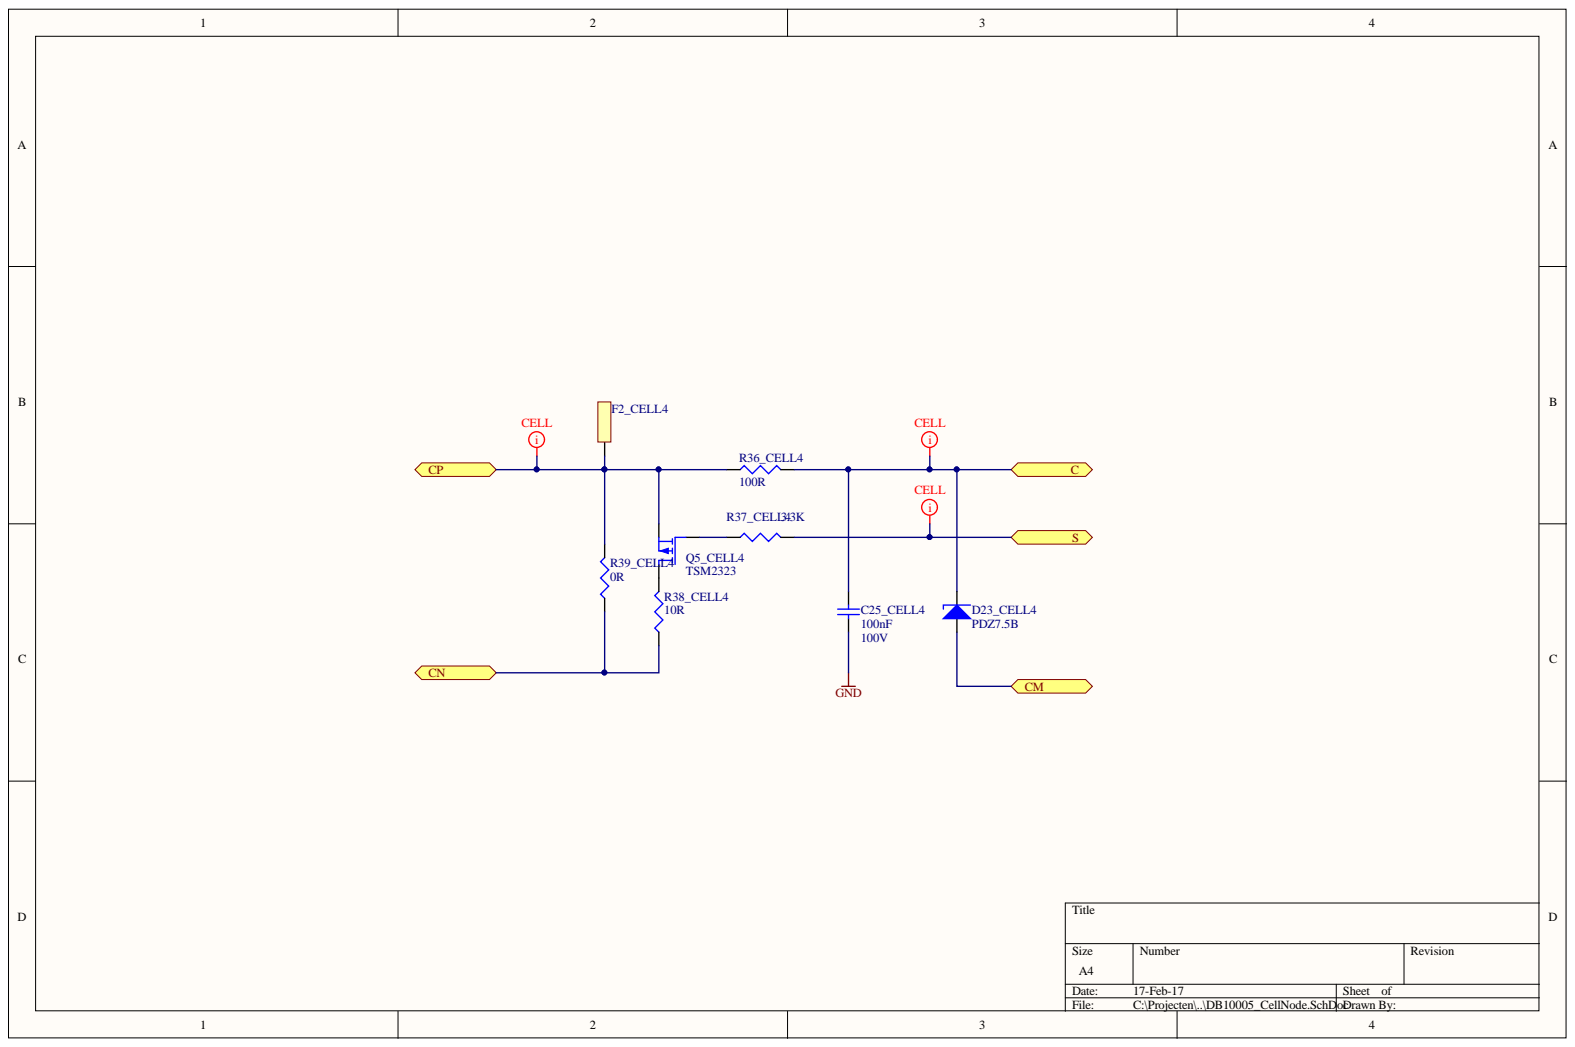
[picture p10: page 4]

Size A4 | Number | Revision

Date: 17-Feb-17 | Sheet of
File: C:\Projecten\..\DB10005_CellNode.SchDocDrawn By:

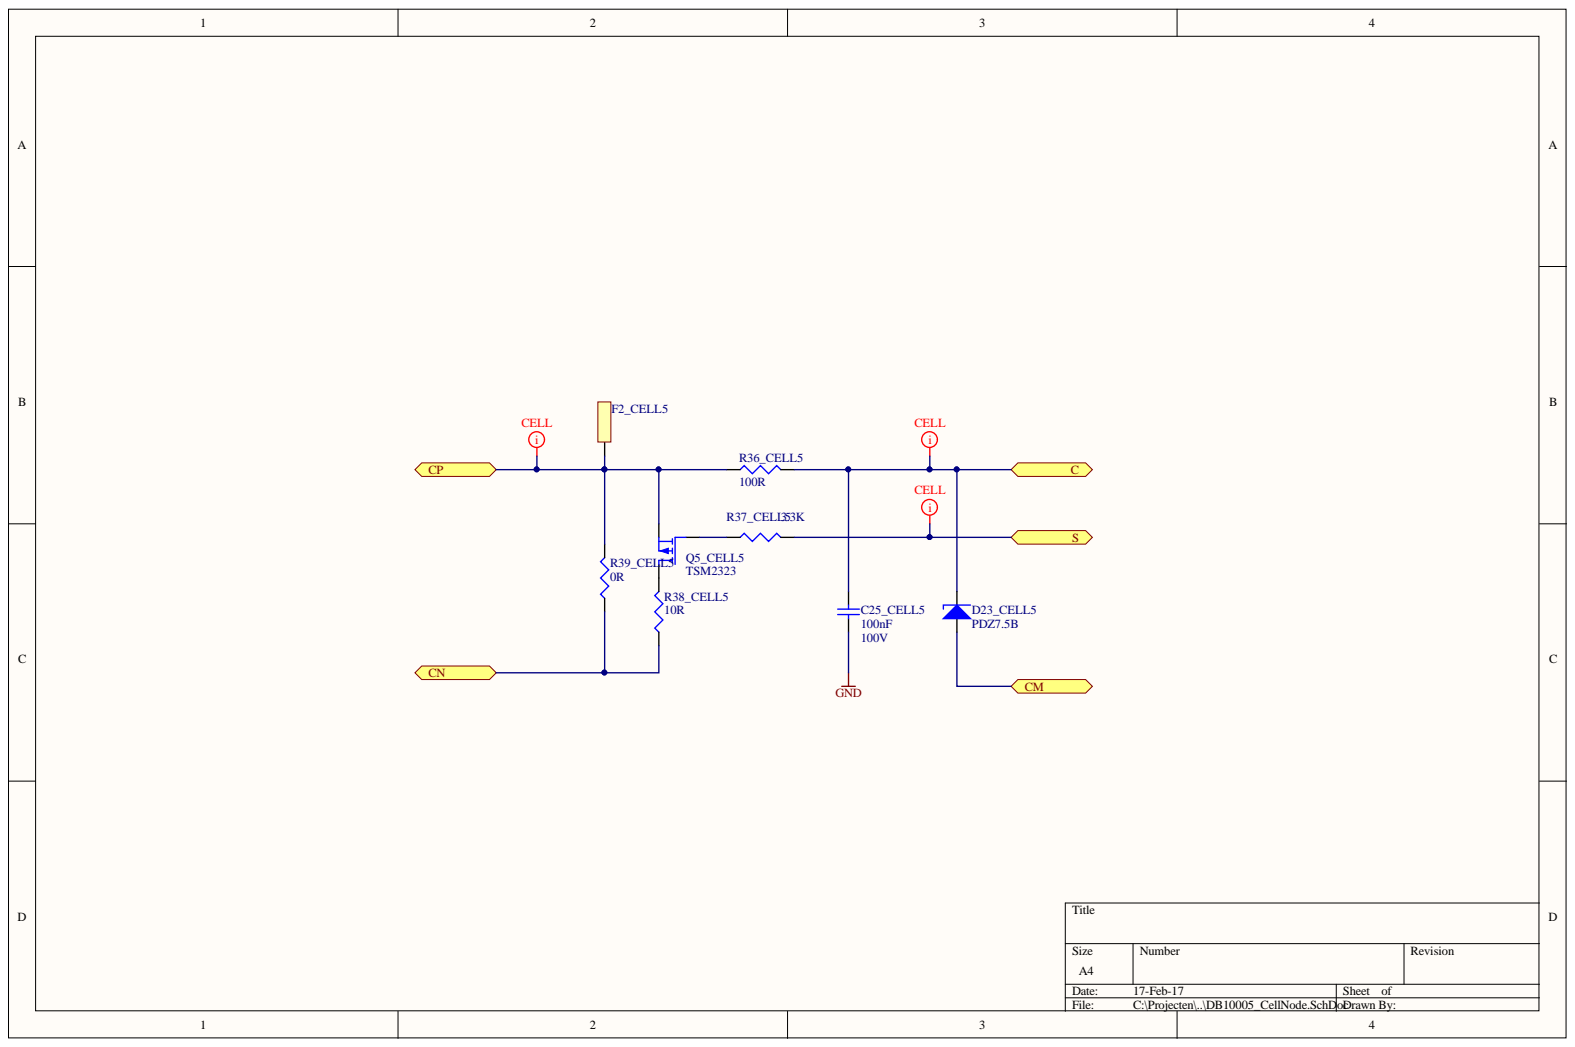
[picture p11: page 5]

Size A4 | Number | Revision

Date: 17-Feb-17 | Sheet of
File: C:\Projecten\..\DB10005_CellNode.SchDocDrawn By:

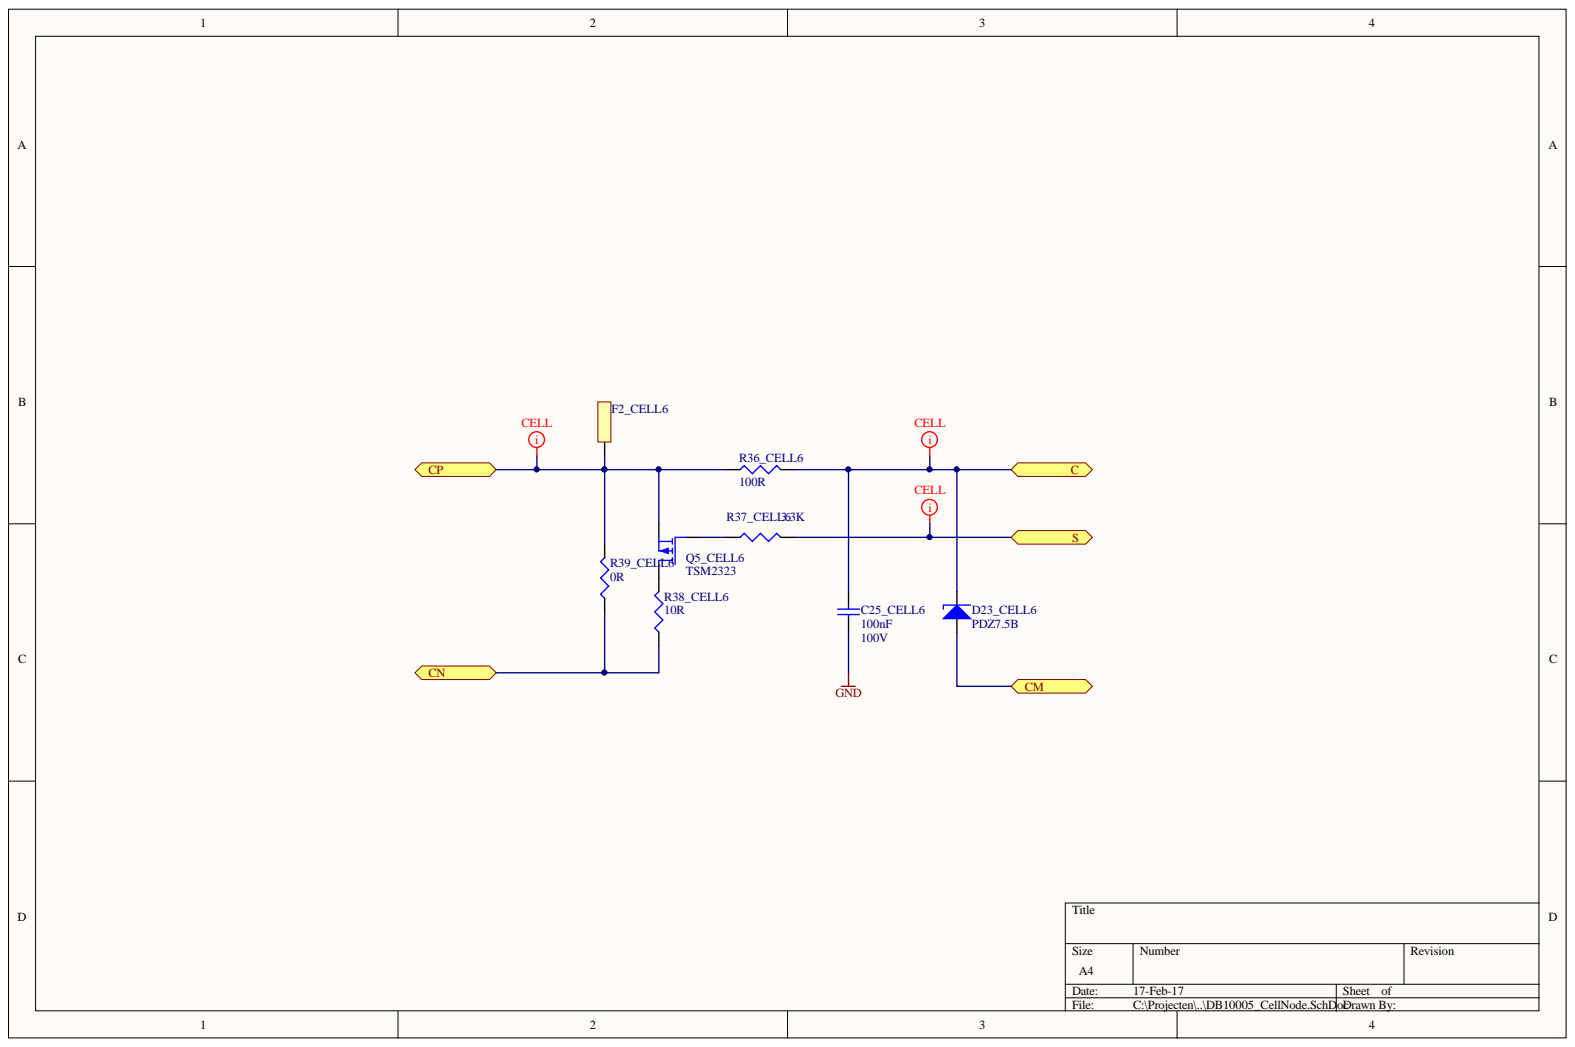
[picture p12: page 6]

Size A4 | Number | Revision

Date: 17-Feb-17 | Sheet of
File: C:\Projecten\..\DB10005_CellNode.SchDocDrawn By:

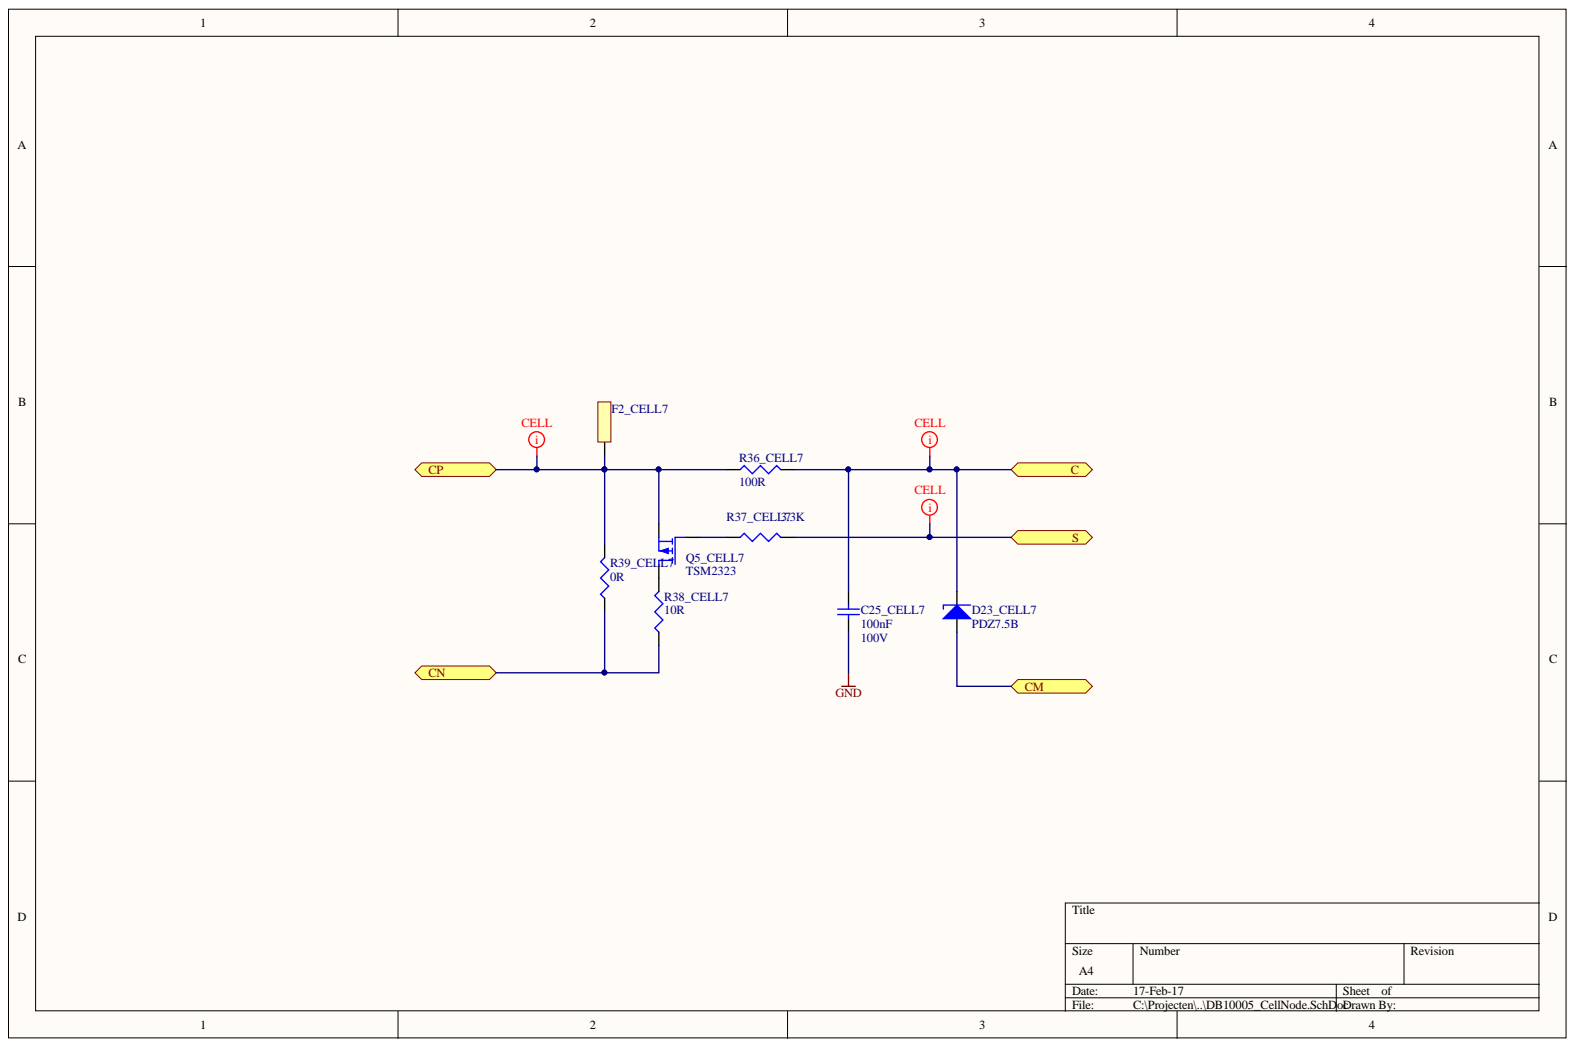
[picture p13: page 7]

Size A4 | Number | Revision

Date: 17-Feb-17 | Sheet of
File: C:\Projecten\..\DB10005_CellNode.SchDocDrawn By:

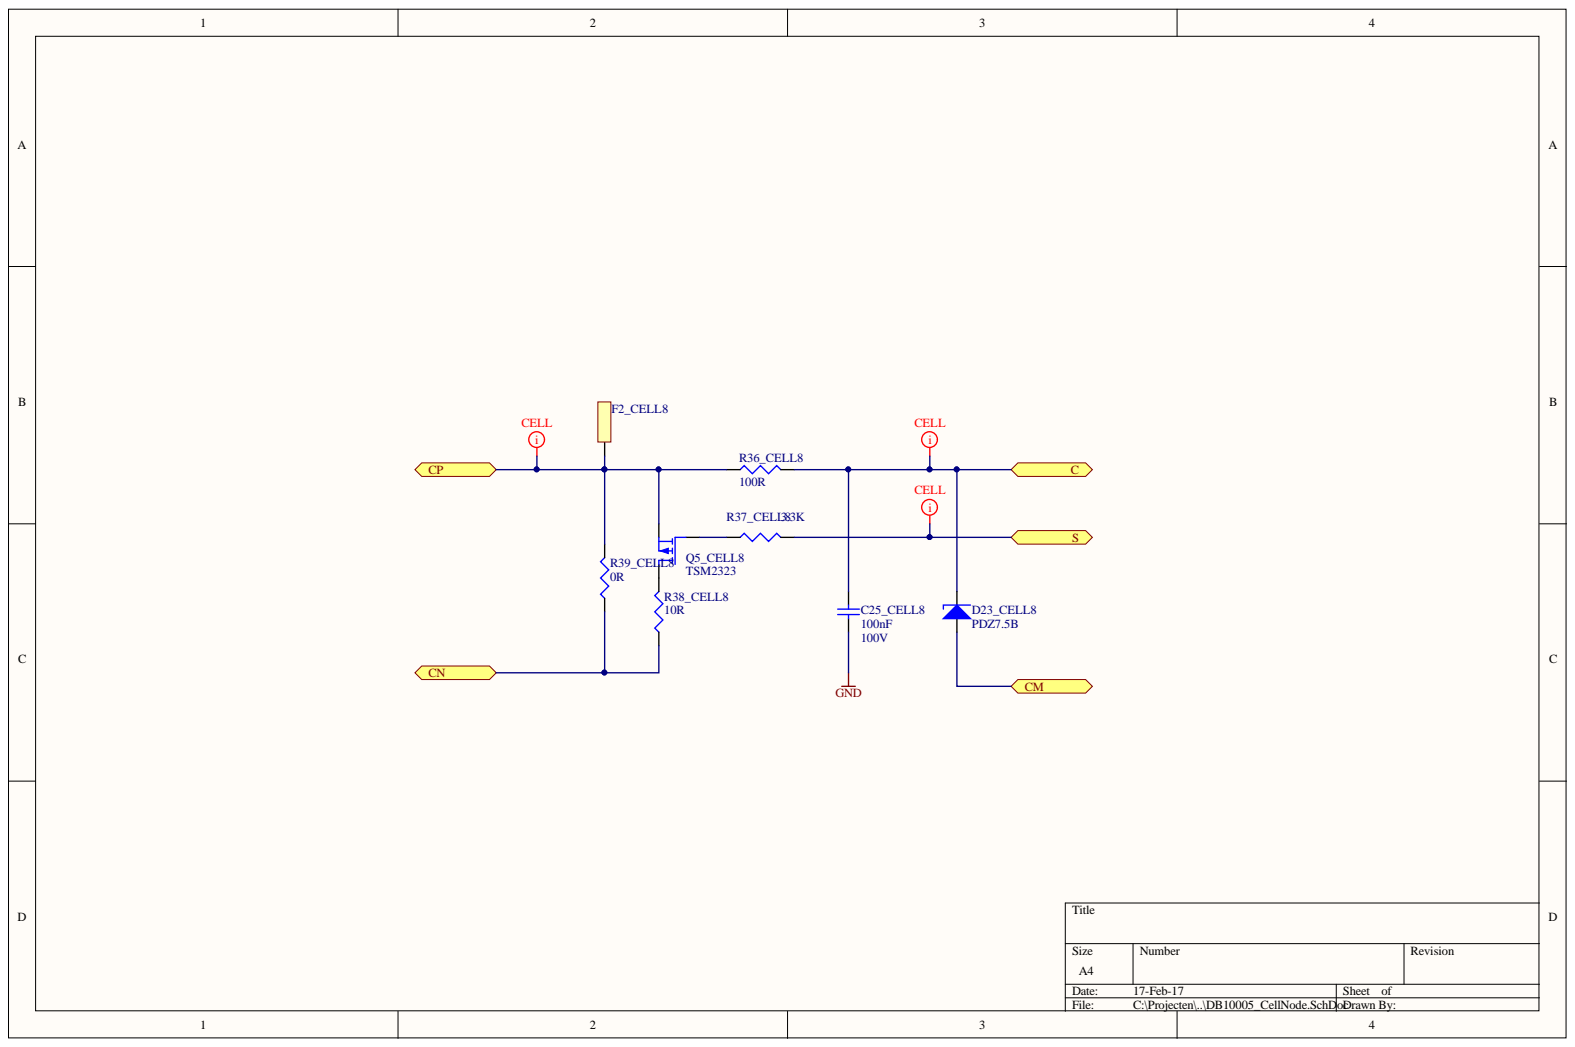
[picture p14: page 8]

Size A4 | Number | Revision

Date: 17-Feb-17 | Sheet of
File: C:\Projecten\..\DB10005_CellNode.SchDocDrawn By:

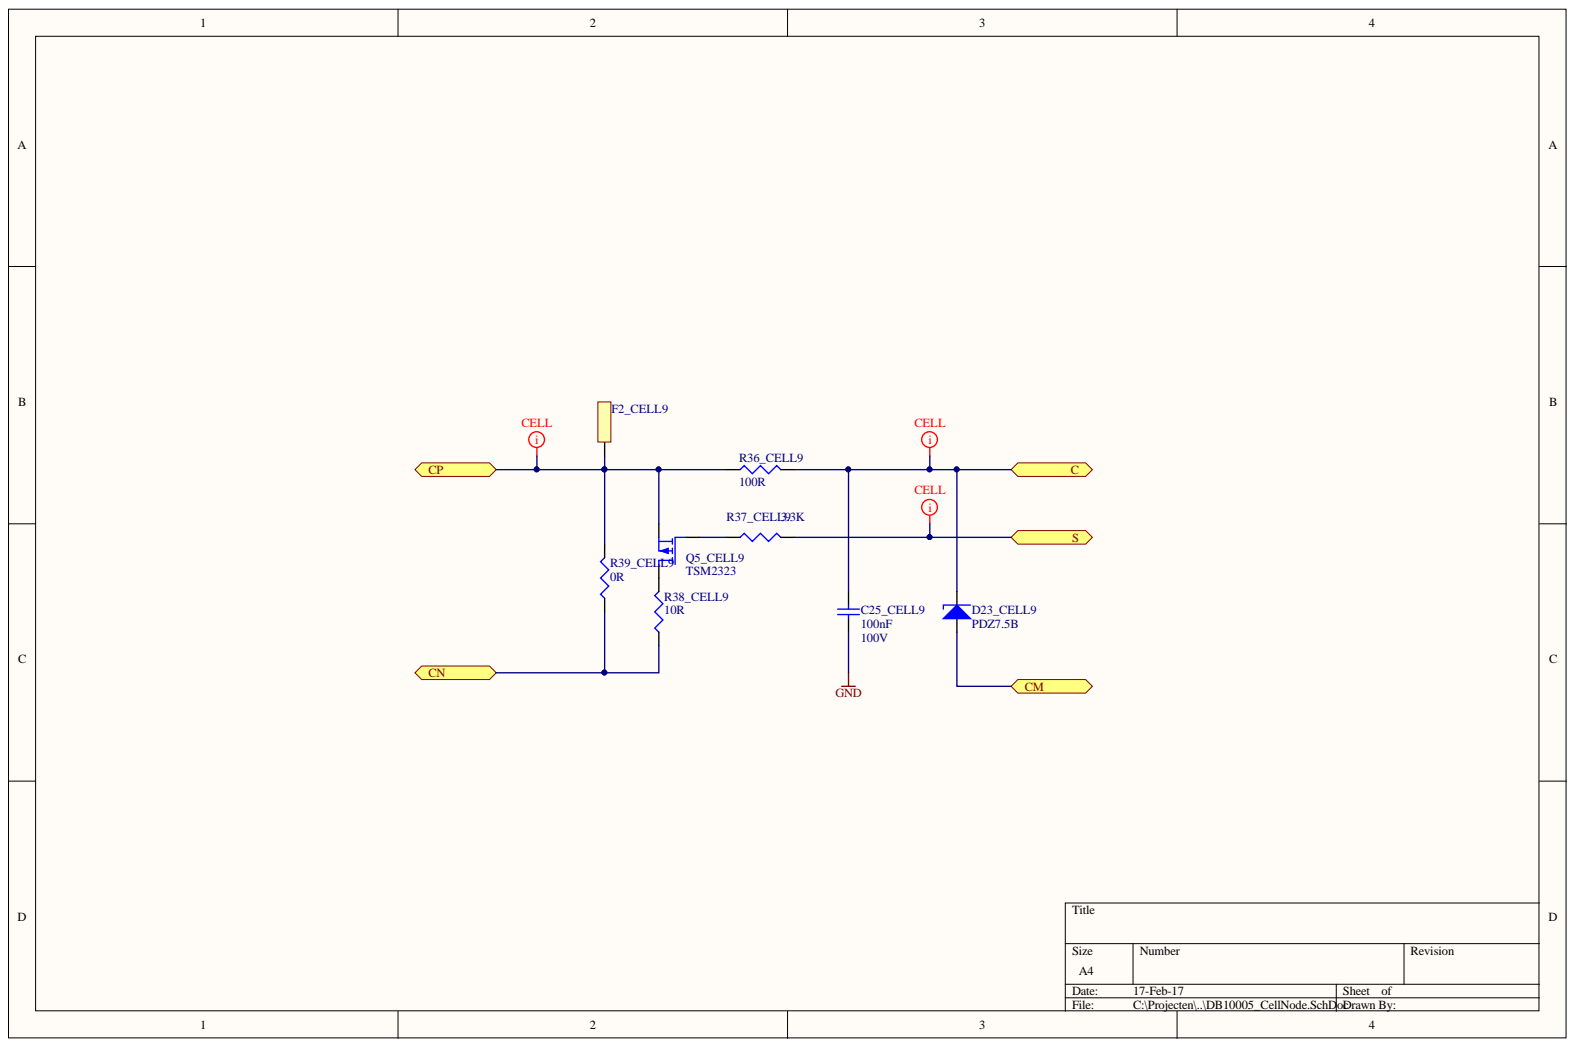
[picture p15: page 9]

Size A4 | Number | Revision

Date: 17-Feb-17 | Sheet of
File: C:\Projecten\..\DB10005_CellNode.SchDocDrawn By:

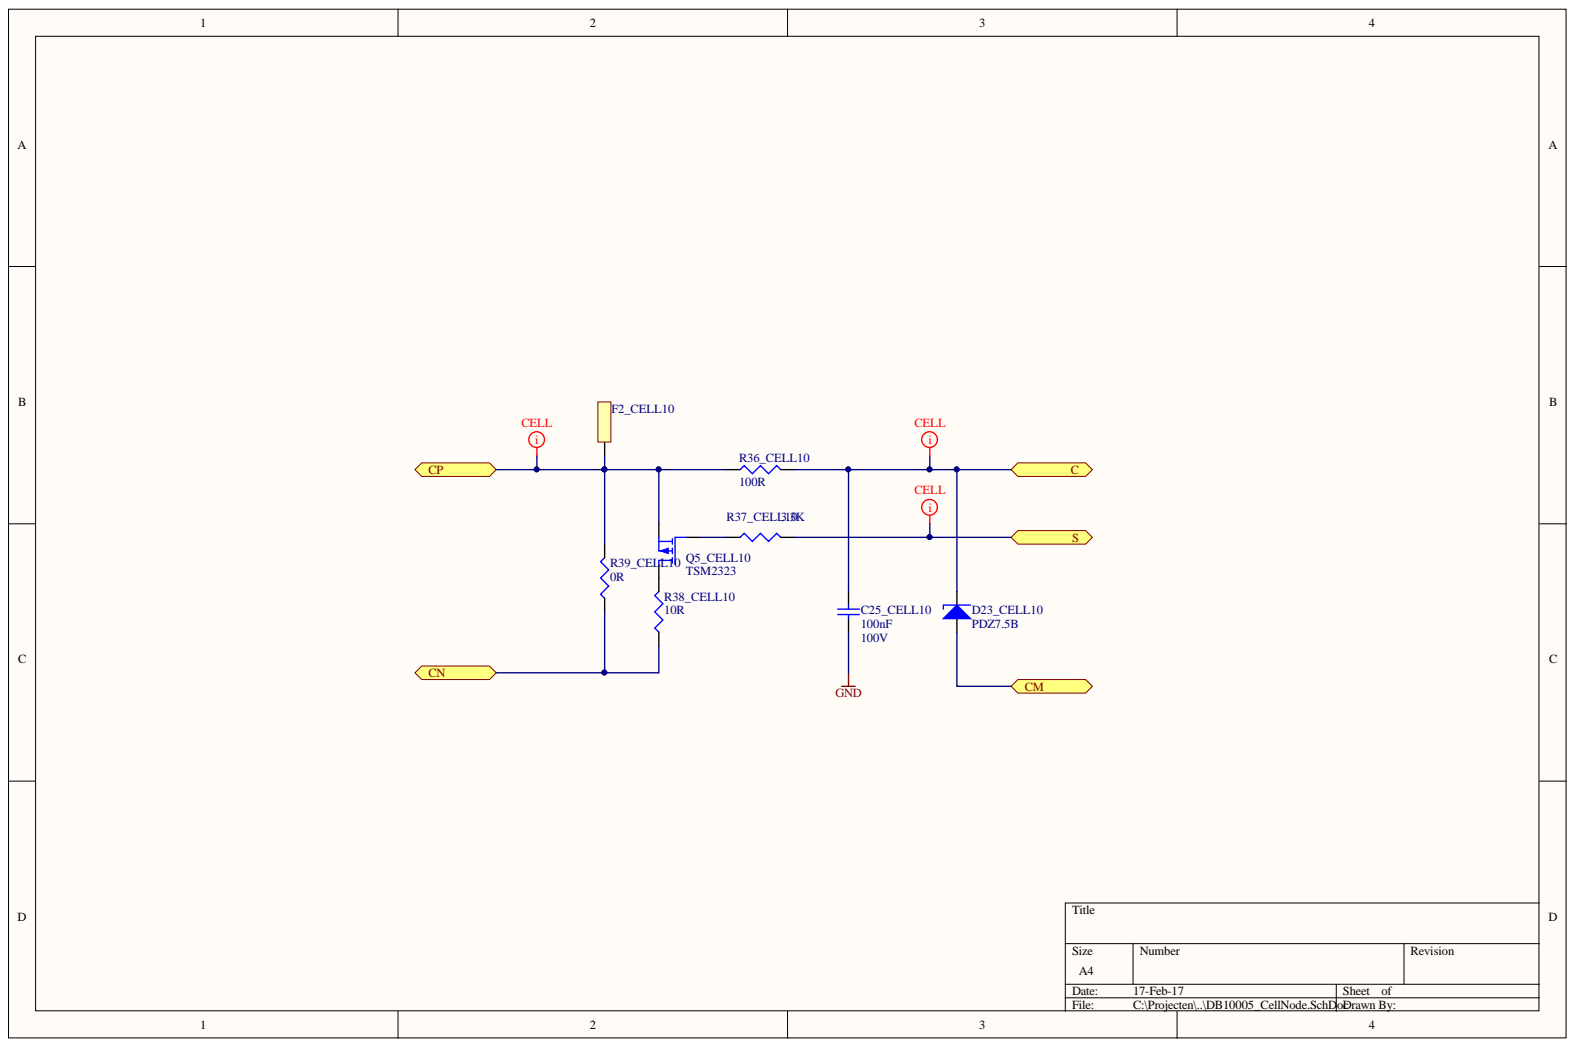
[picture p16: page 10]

Size A4 | Number | Revision

Date: 17-Feb-17 | Sheet of
File: C:\Projecten\..\DB10005_CellNode.SchDocDrawn By:

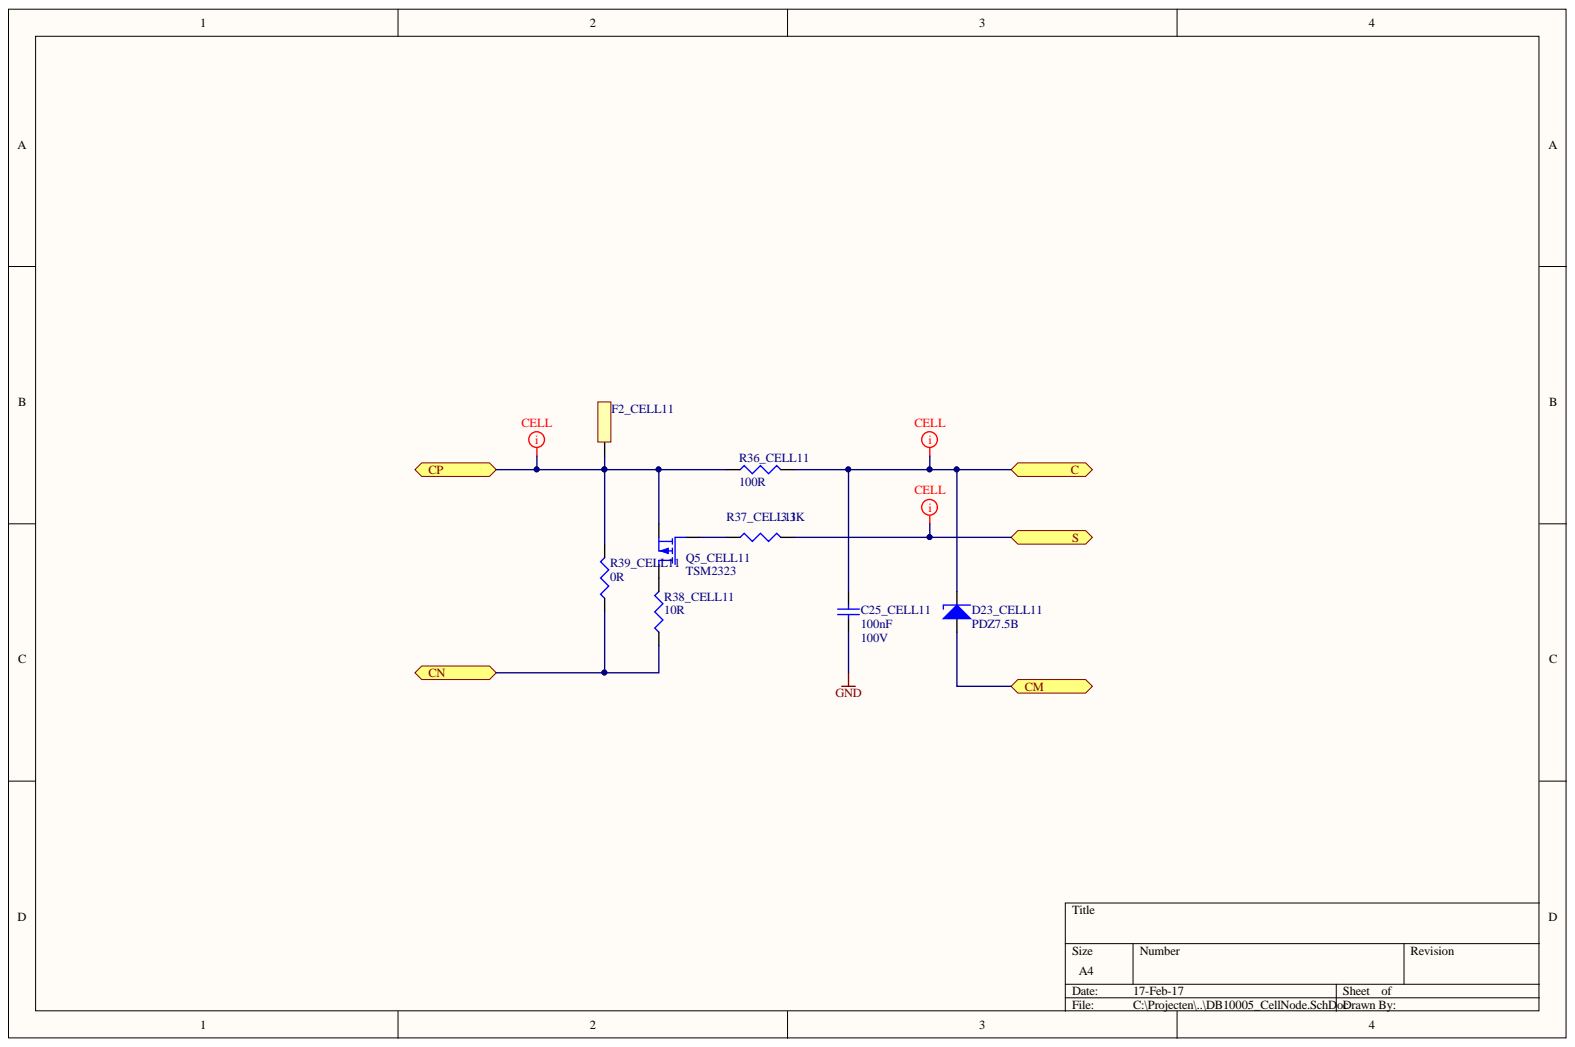
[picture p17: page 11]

Size A4 | Number | Revision

Date: 17-Feb-17 | Sheet of
File: C:\Projecten\..\DB10005_CellNode.SchDocDrawn By:

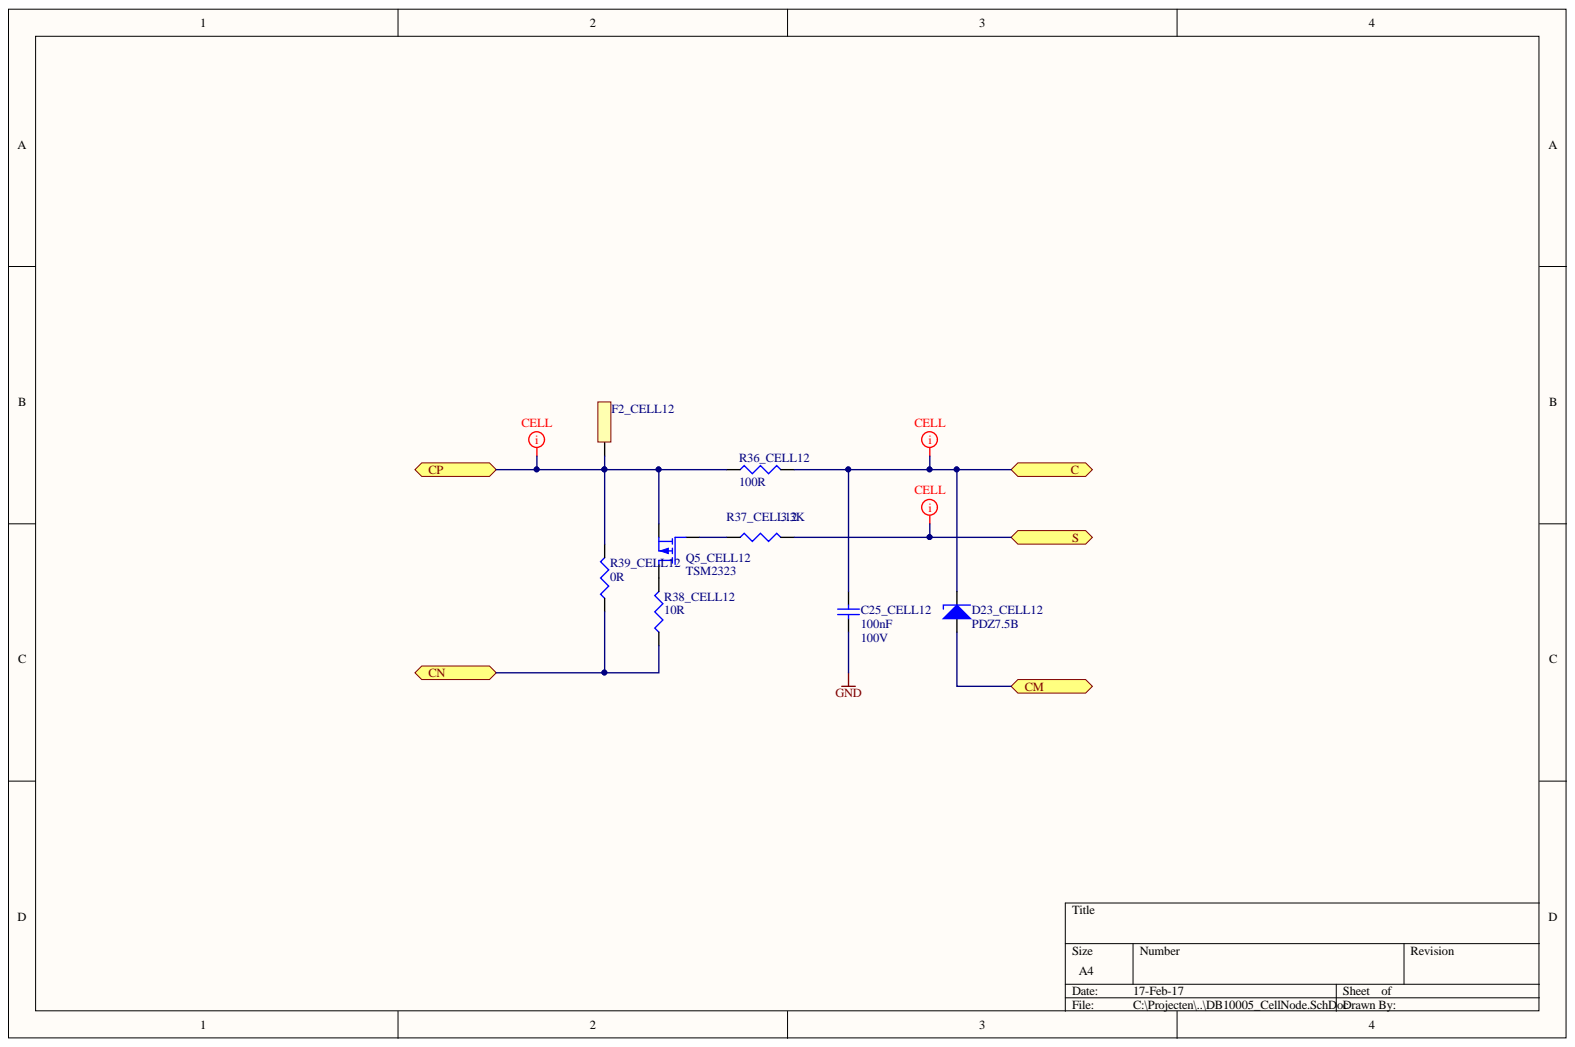
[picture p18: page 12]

Size A4 | Number | Revision

Date: 17-Feb-17 | Sheet of
File: C:\Projecten\..\DB10005_CellNode.SchDocDrawn By:


C A N L | 12345
5 V _ C A N

TopLe v el sc h T i t l e | **** *


3 1
3 2

3 4
3 5
3 6 4 0


U S B _T X | 1 | 2
U S B _R X | 1 | 3
S S | 1 | 4
S C K | | 1 | 5

MI S O | | 1 | 6
MO S I | | 1 | 7

C A N _T X | 3 | 3 | 2 7 S P I 2_MI S O | 2
SWD I O | 3 | 4 | 2 8 S P I 2_MO S I | 3
SWC L K | 3 | 7 | 2 S A F E T Y | 4
B u z z e r | 3 | 8 | | 5

SWD

Controlle r T i t l e | **** *


Power management Title | * * * * *

A4 Size: | * Number: | * Revision:

Date: 17-Feb-17 Time: 01:02:04 | | Sheet 4 of 7
File: C:\Projecten\DieBieMS\GitHub\Hardware\DB10005_PowerManagement.SchDoc


CELL i | R31

Power switching Title | * * * * *

Size: A3 | Number: * | Revision: *

Date: 17-Feb-17 Time: 01:02:04 | | Sheet 5 of 7

C:\Projecten\DieBieMS\GitHub\Hardware\DB10005_PowerSwitch.SchDoc


CAN interface Title | * * * * *

A4 Size: | * Number: | * Revision:

Date: 17-Feb-17 Time: 01:02:04 | | Sheet 6 of 7
File: C:\Projecten\DieBieMS\GitHub\Hardware\DB10005_CAN.SchDoc


USB Serial | **** *

A 4 | Numbe r : | * R evision:

D ate : 17-F eb-17 Time : 01:02:04 | | She e t 7 of 7
File : C:\P roje cten\Die BieMS\GitHub\H ardw are\D B10005_U S B S e rial. S chDoc

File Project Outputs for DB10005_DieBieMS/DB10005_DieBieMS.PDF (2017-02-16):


Numbe r | R evision

: 17-F eb-17 | She et of
File : C:\P roje cten\. .\D B10005_C ellNode . S chDocD | r a wn By:


Numbe r | R evision

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


Numbe r | R evision

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


Numbe r | R evision

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


Numbe r | R evision

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


Numbe r | R evision

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


Numbe r | R evision

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


Numbe r | R evision

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


Numbe r | R evision

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


Numbe r | R evision

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


Numbe r | R evision

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


Numbe r | R evision

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


C A N L | 12345
5 V _ C A N

TopLe v el sc h T i t l e | **** *


3 1
3 2

3 4
3 5
3 6 4 0


U S B _T X | 1 | 2
U S B _R X | 1 | 3
S S | 1 | 4
S C K | | 1 | 5

MI S O | | 1 | 6
MO S I | | 1 | 7

C A N _T X | 3 | 3 | 2 7 S P I 2_MI S O | 2
SWD I O | 3 | 4 | 2 8 S P I 2_MO S I | 3
SWC L K | 3 | 7 | 2 S A F E T Y | 4
B u z z e r | 3 | 8 | | 5

SWD

Controlle r T i t l e | **** *


Power management Title | * * * * *

A4 Size: | * Number: | * Revision:

Date: 17-Feb-17 Time: 00:49:58 | | Sheet 4 of 7
File: C:\Projecten\DieBieMS\GitHub\Hardware\DB10005_PowerManagement.SchDoc


CELL i | R31

Power switching Title | * * * * *

Size: A3 | Number: * | Revision: *

Date: 17-Feb-17 Time: 00:49:58 | | Sheet 5 of 7

C:\Projecten\DieBieMS\GitHub\Hardware\DB10005_PowerSwitch.SchDoc


CAN interface Title | * * * * *

A4 Size: | * Number: | * Revision:

Date: 17-Feb-17 Time: 00:49:58 | | Sheet 6 of 7
File: C:\Projecten\DieBieMS\GitHub\Hardware\DB10005_CAN.SchDoc


USB Serial | **** *

A 4 | Numbe r : | * R evision:

D ate : 17-F eb-17 Time : 00:49:58 | | She e t 7 of 7
File : C:\P roje cten\Die BieMS\GitHub\H ardw are\D B10005_U S B S e rial. S chDoc

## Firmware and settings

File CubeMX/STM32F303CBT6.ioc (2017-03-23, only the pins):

Mcu.UserName=STM32F303CBTx
PA0.GPIO_Label=ChargeDetect
PA0.Signal=GPIO_Input
PA1.GPIO_Label=VoutSense
PA1.Signal=ADC1_IN2
PA10.GPIO_Label=ISL_SDA
PA10.Signal=I2C2_SDA
PA11.Signal=CAN_RX
PA12.Signal=CAN_TX
PA13.Signal=SYS_JTMS-SWDIO
PA14.Signal=SYS_JTCK-SWCLK
PA15.GPIO_Label=Buzzer
PA15.Signal=GPIO_Output
PA2.GPIO_Label=BOOTLOADER_TX
PA2.Signal=USART2_TX
PA3.GPIO_Label=BOOTLOADER_RX
PA3.Signal=USART2_RX
PA4.GPIO_Label=LTC_CS
PA4.Signal=SPI1_NSS
PA5.GPIO_Label=LTC_SCK
PA5.Signal=SPI1_SCK
PA6.GPIO_Label=LTC_MISO
PA6.Signal=SPI1_MISO
PA7.GPIO_Label=LTC_MOSI
PA7.Signal=SPI1_MOSI
PA8.GPIO_Label=ISL_INT
PA8.Signal=GPIO_Input
PA9.GPIO_Label=ISL_SCL
PA9.Signal=I2C2_SCL
PB0.GPIO_Label=ChargeEnable
PB0.Signal=GPIO_Output
PB1.GPIO_Label=StatusLED
PB1.Signal=GPIO_Output
PB10.GPIO_Label=DischargeEnable
PB10.Signal=GPIO_Output
PB11.GPIO_Label=PreChargeEnable
PB11.Signal=GPIO_Output
PB12.Signal=SPI2_NSS
PB13.Signal=SPI2_SCK
PB14.Signal=SPI2_MISO
PB15.Signal=SPI2_MOSI
PB2.GPIO_Label=SwitchEnable
PB2.Signal=GPIO_Output
PB3.GPIO_Label=PowerLED
PB3.Signal=GPIO_Output
PB4.GPIO_Label=PowerButton
PB4.Signal=GPIO_Input
PB5.GPIO_Label=PowerEnable
PB5.Signal=GPIO_Output
PB6.GPIO_Label=OLED_SCL
PB6.Signal=I2C1_SCL
PB7.GPIO_Label=OLED_SDA
PB7.Signal=I2C1_SDA
PB8.GPIO_Label=OLED_RST
PB8.Signal=GPIO_Output
PF0-OSC_IN.Signal=RCC_OSC_IN
PF1-OSC_OUT.Signal=RCC_OSC_OUT

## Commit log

2016-04-30 Added pdf print of schematic
2016-04-30 Connected micro controller
    [DB10005_CAN.SchDoc, DB10005_Controller.SchDoc, DB10005_DieBieMS.PrjPcb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]
2016-05-01 Implemented current sensor and optimised uC connections.
    [DB10005_BatteryStackMonitor.SchDoc, DB10005_Controller.SchDoc, DB10005_DieBieMS.PrjPcb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]
2016-05-02 Changed to ISL current and voltage sensor, new connection mapping of uC and started implementing power switching circuit.
    [DB10005_BMS.PcbDoc, DB10005_BatteryStackMonitor.SchDoc, DB10005_CAN.SchDoc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]
2016-05-04 Progress on the cell balancing circuit.
    [DB10005_BatteryStackMonitor.SchDoc, DB10005_CellNode.SchDoc, DB10005_DieBieMS.PrjPcb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]
2016-06-02 Updated power management / switching.
    [DB10005_BatteryStackMonitor.SchDoc, DB10005_CellNode.SchDoc, DB10005_Controller.SchDoc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]
2016-06-02 Updated schematic prints output.
2016-06-13 Made rough placement of components on the PCB.
    [DB10005_BatteryStackMonitor.SchDoc, DB10005_CellNode.SchDoc, DB10005_Controller.SchDoc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]
2016-06-15 Routing and design rule updates.
    [DB10005_PowerManagement.SchDoc, DB10005_PowerSwitch.SchDoc, DB10005_TopLevel.SchDoc]
2016-06-15 More routing.
    [DB10005_Controller.SchDoc]
2016-06-16 Finish gross routing, next up; polishing and tweaking :).
    [DB10005_TopLevel.SchDoc]
2016-06-18 Finished polishing design + generated production files. This PCB is send to production as V0_1.
    [Bill of Materials-DB10005_DieBieMS.csv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]
2016-10-15 Moved some components around. Removed memory chip and added SD card holder.
    [Bill of Materials-DB10005_DieBieMS.csv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]
2016-12-07 Added shunt resistor, SD card holder and savety connection between LTC and PowerStage.
    [DB10005_BatteryStackMonitor.SchDoc, DB10005_CAN.SchDoc, DB10005_Controller.SchDoc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]
2016-12-08 Connected Safety pin to uC as well. Generated production files an send them to FAB.
    [Bill of Materials-DB10005_DieBieMS.csv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]
2017-02-16 Added some pictures. Updraded pcb version to 0.4 and updates input diode bypass.
    [DB10005_TopLevel.SchDoc]
2017-02-16 Added schematic to fix link on forum.
    [DB10005_PowerManagement.SchDoc]
2017-03-23 Added pictures.
    [DB10005_DieBieMS.PrjPcb]
2017-07-16 Updated BOM and component choiches.
    [Bill of Materials-DB10005_DieBieMS.csv, DB10005_BatteryStackMonitor.SchDoc, DB10005_DieBieMS.PrjPcb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]
2017-08-08 Updated bom with other balance resistors and logic fuse. Updates footprints and improved routing.
    [Bill of Materials-DB10005_DieBieMS(Production).csv, Bill of Materials-DB10005_DieBieMS.csv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]
2017-08-17 Updated .step file of the PCB.
    [DB10005_DieBieMS.PrjPcb]
2017-08-17 Added inches based PCB data for OSH Park.
    [Bill of Materials-DB10005_DieBieMS(Production).csv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]
2017-08-17 Fixed a few things. OSHPark now eats the gerber and drill files
    [Bill of Materials-DB10005_DieBieMS(Production).csv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]
2017-09-05 Fixed small mistake in NTC circuit, the complementing resistor had the wrom value.
    [Bill of Materials-DB10005_DieBieMS(Production).csv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]
2017-11-30 Took notch out of PCB for easier connector placement.
    [DB10005_PowerSwitch.SchDoc, DB10005_TopLevel.SchDoc]
2017-12-16 Updated production files to be more complete. The C7 that was missing is now in the BOM.
    [Bill of Materials-DB10005_DieBieMS(Production).csv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]
2017-12-16 Updated version text on PCB.
2018-01-03 Latest version before switching to altium 18.
    [DB10005_TopLevel.SchDoc]
2018-02-16 Generated prod files.
    [Bill of Materials-DB10005_DieBieMS(Production).csv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]
2018-04-18 Hardware version is now at V0.7, added an alternate option for the power stage NTC, updated the pullup resistors for the NTC connected to the LTC, these were 10k but that value is to low for the LTC 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
    [Bill of Materials-DB10005_DieBieMS(Production).csv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]
2018-07-05 Now tied BOOT0 to GND. This resolves a few isseus where the uC doensnt boot when the PCB is polluted with flux or water.
    [DB10005_BMS.GBL, DB10005_BMS.GBO, DB10005_BMS.GBP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]
2018-08-25 Added 3DFiles back in the repo.
    [DB10005_TopLevel.SchDoc]
2018-10-27 Added testpoints.
    [DB10005_BatteryStackMonitor.SchDoc, DB10005_Controller.SchDoc, DB10005_PowerManagement.SchDoc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]
2018-10-27 Updated rev to 0.9, new production outputs generated.
    [DB10005_BMS.GBL, DB10005_BMS.GBO, DB10005_BMS.GBP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]
